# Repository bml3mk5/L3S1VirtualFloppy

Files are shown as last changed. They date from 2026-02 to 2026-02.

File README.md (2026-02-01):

# バーチャルフロッピーカード for 日立ベーシックマスターレベル3 / MB-S1

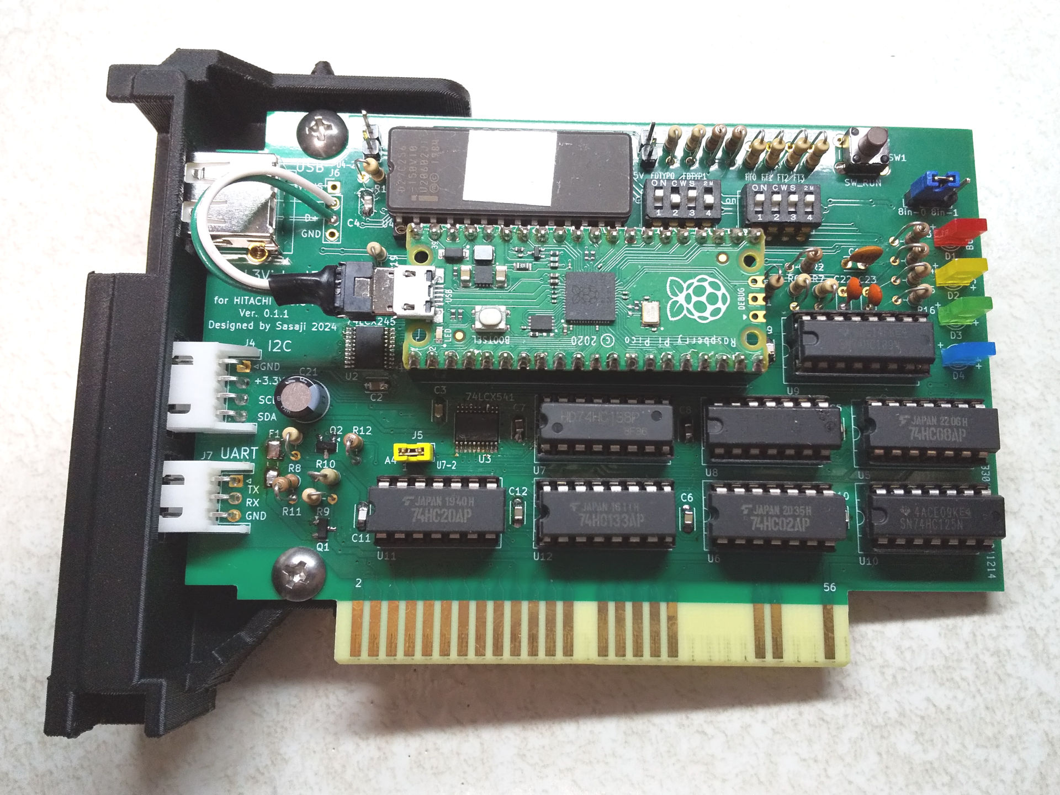
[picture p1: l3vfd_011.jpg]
L3VirtualFloppy Main

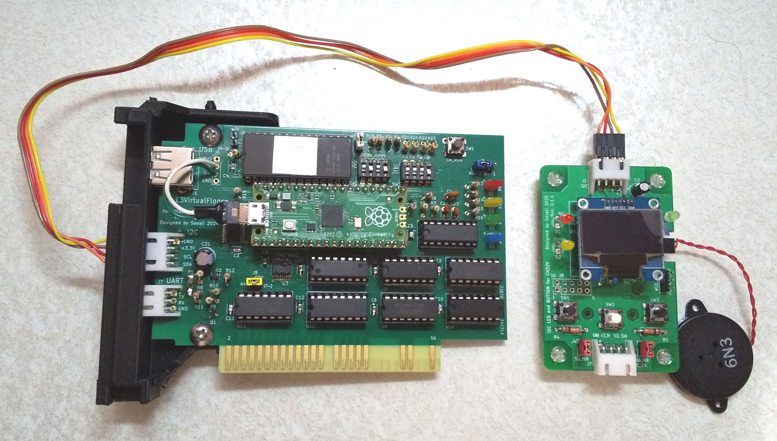
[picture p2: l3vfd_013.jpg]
L3VirtualFloppy Main + Controller

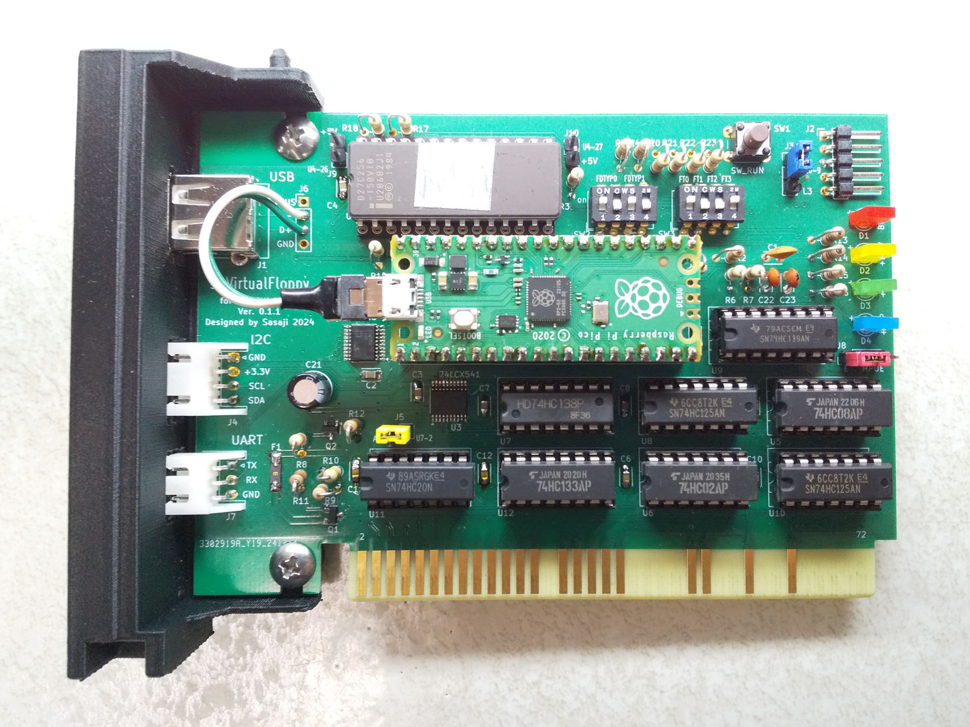
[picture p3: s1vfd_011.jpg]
S1VirtualFloppy Main

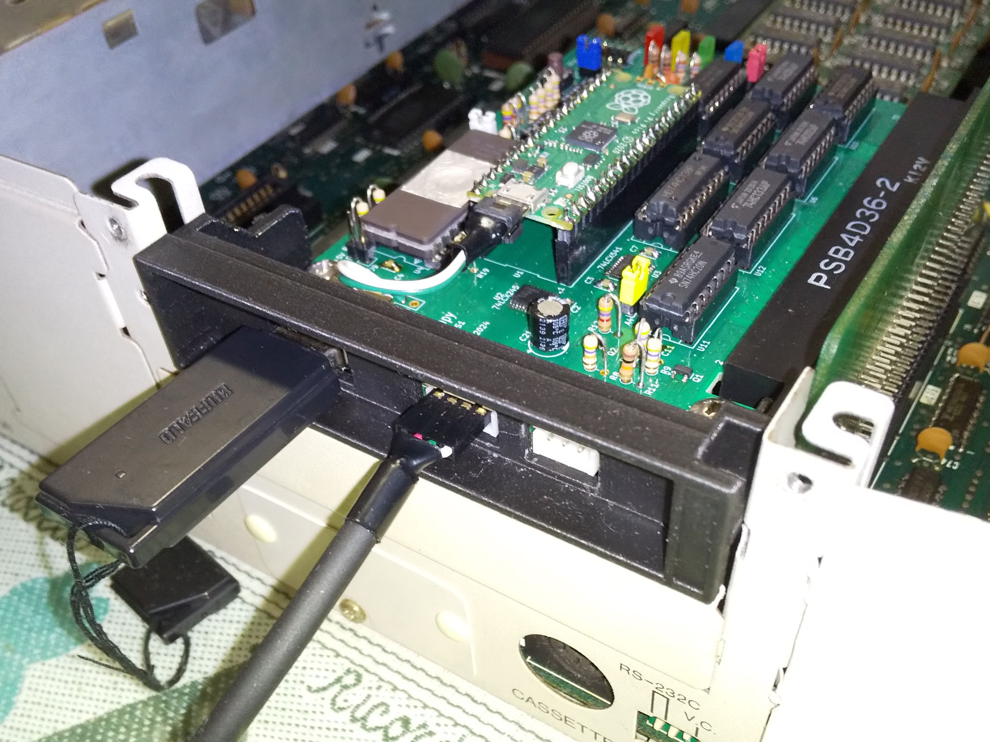
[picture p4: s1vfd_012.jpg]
S1VirtualFloppy Installed

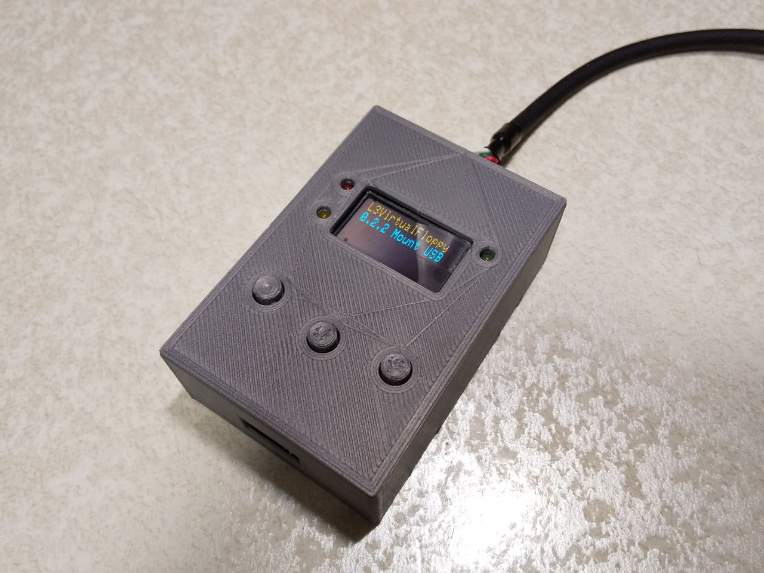
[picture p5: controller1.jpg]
Controller


## フォルダ構成

    3DModel/ ....................... 背面カバーの3Dモデル
      BML3/ .......................... 日立ベーシックマスターレベル3用の3Dモデル
      MBS1/ .......................... 日立MB-S1用の3Dモデル
    Board/ ......................... 基板設計
      BML3/ .......................... 日立ベーシックマスターレベル3用の基板設計
      MBS1/ .......................... 日立MB-S1用の基板設計
    Documents/ ..................... 説明書など
      BML3/ .......................... 日立ベーシックマスターレベル3用の説明書
      MBS1/ .......................... 日立MB-S1用の説明書
    Software/ ...................... ソフトウェア
      Controller/ .................... 本体カード用コントローラー
      Main/ .......................... 本体用(Pico SDK v2.0.0 + Visual Code(Cmake))
        pico_l3/ ....................... 日立ベーシックマスターレベル3用のソフトウェア
        pico_s1/ ....................... 日立MB-S1用のソフトウェア

-----
# Virtual Floppy Card for HITACHI Basic Master Level3 / MB-S1

## Folders

    3DModel/ ....................... The 3d models of back cover
      BML3/ .......................... for HITACHI Basic Master Level3
      MBS1/ .......................... for HITACHI MB-S1
    Board/ ......................... The circuit board design
      BML3/ .......................... for HITACHI Basic Master Level3
      MBS1/ .......................... for HITACHI MB-S1
    Documents/ ..................... Documents
      BML3/ .......................... for HITACHI Basic Master Level3
      MBS1/ .......................... for HITACHI MB-S1
    Software/ ...................... Software
      Controller/ .................... Controller for main card
      Main/ .......................... Main card (Pico SDK v2.0.0 + Visual Code(Cmake))
        pico_l3/ ....................... for HITACHI Basic Master Level3
        pico_s1/ ....................... for HITACHI MB-S1

-----
 MailTo: Sasaji (sasaji@s-sasaji.ddo.jp)
 * My Webpage: http://s-sasaji.ddo.jp/bml3mk5/
 * GitHub:     https://github.com/bml3mk5/L3S1VirtualFloppy
 * X(Twitter): https://x.com/bml3mk5

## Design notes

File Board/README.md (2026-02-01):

# バーチャルフロッピーカード for 日立ベーシックマスターレベル3 / MB-S1 基板設計

## 使用ツール

 * KiCAD 8

## フォルダ構成

    BML3/ .......................... 日立ベーシックマスターレベル3用
    Controller/ .................... 本体カード用コントローラー
    MBS1/ .......................... 日立MB-S1用

-----
# The Circuit Board Design of the Virtual Floppy Card for HITACHI Basic Master Level3 / MB-S1

## Using Tools

 * KiCAD 8

## Folders

    BML3/ .......................... for HITACHI Basic Master Level3
    Controller/ .................... Controller for main card
    MBS1/ .......................... for HITACHI MB-S1

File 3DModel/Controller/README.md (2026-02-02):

# ケースの3Dモデル for コントローラー

    I2C_LED_BTN.FCStd ........... FreeCAD 1.0を使用した3Dモデル設計ファイル

 * ケース上側

       I2C_LED_BTN-Body.3mf ........ UltiMaker Cura 5.9の設定ファイル
       I2C_LED_BTN-Body.stl ........ FreeCADからエクスポートした3Dモデル
       I2C_LED_BTN-Body.gcode ...... 3Dプリンター(Anycube Mega Zero 2.0)用Gcode

 * ケース下側

       I2C_LED_BTN-Body001.3mf ..... UltiMaker Cura 5.9の設定ファイル
       I2C_LED_BTN-Body001.stl ..... FreeCADからエクスポートした3Dモデル
       I2C_LED_BTN-Body001.gcode ... 3Dプリンター(Anycube Mega Zero 2.0)用Gcode

 * ボタン部分

       I2C_LED_BTN-Body002.3mf ..... UltiMaker Cura 5.9の設定ファイル
       I2C_LED_BTN-Body002.stl ..... FreeCADからエクスポートした3Dモデル
       I2C_LED_BTN-Body002.gcode ... 3Dプリンター(Anycube Mega Zero 2.0)用Gcode

-----
# The 3D models of enclosure for controller

    I2C_LED_BTN.FCStd ........... 3D model design file using FreeCAD 1.0

 * Upper side

       I2C_LED_BTN-Body.3mf ........ Configure file on UltiMaker Cura 5.9
       I2C_LED_BTN-Body.stl ........ Exported 3d model from FreeCAD
       I2C_LED_BTN-Body.gcode ...... Gcode for 3D printer (Anycube Mega Zero 2.0)

 * Lower side

       I2C_LED_BTN-Body001.3mf ..... Configure file on UltiMaker Cura 5.9
       I2C_LED_BTN-Body001.stl ..... Exported 3d model from FreeCAD
       I2C_LED_BTN-Body001.gcode ... Gcode for 3D printer (Anycube Mega Zero 2.0)

 * Parts of the button

       I2C_LED_BTN-Body002.3mf ..... Configure file on UltiMaker Cura 5.9
       I2C_LED_BTN-Body002.stl ..... Exported 3d model from FreeCAD
       I2C_LED_BTN-Body002.gcode ... Gcode for 3D printer (Anycube Mega Zero 2.0)

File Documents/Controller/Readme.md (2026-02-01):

# Controller for Virtual Floppy

## [組立説明書](Assemble_ja.pdf)

## [取扱説明書](Manual_ja.pdf)

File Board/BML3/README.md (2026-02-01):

# 基板設計 for L3VirtualFloppy

## 使用ツール

 * KiCAD 8

## ファイル

    L3VirtualFloppy.kicad_pro ..... プロジェクトファイル for KiCAD
    L3VirtualFloppy.kicad_sch ..... 回路図ファイル for KiCAD
    L3VirtualFloppy.kicad_pcb ..... PCB設計ファイル for KiCAD
    *.kicad_sym ................... シンボルファイル
    *.pretty/ ..................... フットプリントファイル
    *.wrl ......................... 3Dモデルファイル(3Dビュー用)
    gerber_jlc/ ................... ガーバーファイル for JLCPCB

-----
# The Circuit Board Design for L3VirtualFloppy

## Using Tools

 * KiCAD 8

## Files

    L3VirtualFloppy.kicad_pro ..... Project file for KiCAD
    L3VirtualFloppy.kicad_sch ..... Schematics file for KiCAD
    L3VirtualFloppy.kicad_pcb ..... PCB design file for KiCAD
    *.kicad_sym ................... Symbol file
    *.pretty/ ..................... Footprint files
    *.wrl ......................... 3Dmodel file(to use on 3D view)
    gerber_jlc/ ................... Gerber files for JLCPCB

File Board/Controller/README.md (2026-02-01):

# 基板設計 for コントローラー

## 使用ツール

 * KiCAD 8

## ファイル

    I2C_LED_BTN_CH32V.kicad_pro ... プロジェクトファイル for KiCAD
    I2C_LED_BTN_CH32V.kicad_sch ... 回路図ファイル for KiCAD
    I2C_LED_BTN_CH32V.kicad_pcb ... PCB設計ファイル for KiCAD
    *.pretty/ ..................... フットプリントファイル
    *.wrl ......................... 3Dモデルファイル(3Dビュー用)
    gerber_jlc/ ................... ガーバーファイル for JLCPCB

-----
# The Circuit Board Design for Controller

## Using Tools

 * KiCAD 8

## Files

    I2C_LED_BTN_CH32V.kicad_pro ... Project file for KiCAD
    I2C_LED_BTN_CH32V.kicad_sch ... Schematics file for KiCAD
    I2C_LED_BTN_CH32V.kicad_pcb ... PCB design file for KiCAD
    *.pretty/ ..................... Footprint files
    *.wrl ......................... 3Dmodel file(to use on 3D view)
    gerber_jlc/ ................... Gerber files for JLCPCB

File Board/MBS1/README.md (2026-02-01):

# 基板設計 for S1VirtualFloppy

## 使用ツール

 * KiCAD 8

## ファイル

    S1VirtualFloppy.kicad_pro ..... プロジェクトファイル for KiCAD
    S1VirtualFloppy.kicad_sch ..... 回路図ファイル for KiCAD
    S1VirtualFloppy.kicad_pcb ..... PCB設計ファイル for KiCAD
    *.kicad_sym ................... シンボルファイル
    *.pretty/ ..................... フットプリントファイル
    *.wrl ......................... 3Dモデルファイル(3Dビュー用)
    gerber_jlc/ ................... ガーバーファイル for JLCPCB

-----
# The Circuit Board Design for S1VirtualFloppy

## Using Tools

 * KiCAD 8

## Files

    S1VirtualFloppy.kicad_pro ..... Project file for KiCAD
    S1VirtualFloppy.kicad_sch ..... Schematics file for KiCAD
    S1VirtualFloppy.kicad_pcb ..... PCB design file for KiCAD
    *.kicad_sym ................... Symbol file
    *.pretty/ ..................... Footprint files
    *.wrl ......................... 3Dmodel file(to use on 3D view)
    gerber_jlc/ ................... Gerber files for JLCPCB

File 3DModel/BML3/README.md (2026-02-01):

# 背面カバーの3Dモデル for L3VirtualFloppy

    L3BackSideVF2.FCStd ....... FreeCAD 1.0を使用した3Dモデル設計ファイル
    L3BackSideVF2-Body.3mf .... UltiMaker Cura 5.9の設定ファイル
    L3BackSideVF2-Body.stl .... FreeCADからエクスポートした3Dモデル
    L3BackSideVF2-Body.wrl .... FreeCADからエクスポートした3Dモデル(kicad 3Dビューで使用)
    MegaZero2.0/ .............. 3Dプリンター(Anycube Mega Zero 2.0)用Gcode

-----
# The 3D Models of Back Cover for L3VirtualFloppy

    L3BackSideVF2.FCStd ....... 3D model design file using FreeCAD 1.0
    L3BackSideVF2-Body.3mf .... Configure file on UltiMaker Cura 5.9
    L3BackSideVF2-Body.stl .... Exported 3d model from FreeCAD
    L3BackSideVF2-Body.wrl .... Exported 3d model from FreeCAD (to use on kicad 3d view)
    MegaZero2.0/ .............. Gcode for 3D printer (Anycube Mega Zero 2.0)

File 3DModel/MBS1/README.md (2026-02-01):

# 背面カバーの3Dモデル for S1VirtualFloppy

    S1BackSideVF.FCStd ........ FreeCAD 1.0を使用した3Dモデル設計ファイル
    S1BackSideVF-Body.3mf ..... UltiMaker Cura 5.9の設定ファイル
    S1BackSideVF-Body.stl ..... FreeCADからエクスポートした3Dモデル
    S1BackSideVF-Body.wrl ..... FreeCADからエクスポートした3Dモデル(kicad 3Dビューで使用)
    MegaZero2.0/ .............. 3Dプリンター(Anycube Mega Zero 2.0)用Gcode

-----
# The 3D Models of Back Cover for S1VirtualFloppy

    S1BackSideVF.FCStd ........ 3D model design file using FreeCAD 1.0
    S1BackSideVF-Body.3mf ..... Configure file on UltiMaker Cura 5.9
    S1BackSideVF-Body.stl ..... Exported 3d model from FreeCAD
    S1BackSideVF-Body.wrl ..... Exported 3d model from FreeCAD (to use on kicad 3d view)
    MegaZero2.0/ .............. Gcode for 3D printer (Anycube Mega Zero 2.0)

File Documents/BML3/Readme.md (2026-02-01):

# L3VirtualFloppy

## [Assembly Instruction](Assemble_en.pdf)
## [組立説明書](Assemble_ja.pdf)

## [User's Manual](Manual_en.pdf)
## [取扱説明書](Manual_ja.pdf)

## [Schematics](L3VirtualFloppy_sch.png)
## [回路図](L3VirtualFloppy_sch.png)

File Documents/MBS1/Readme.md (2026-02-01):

# S1VirtualFloppy

## [Assembly Instruction](Assemble_en.pdf)
## [組立説明書](Assemble_ja.pdf)

## [User's Manual](Manual_en.pdf)
## [取扱説明書](Manual_ja.pdf)

## [Schematics](S1VirtualFloppy_sch.png)
## [回路図](S1VirtualFloppy_sch.png)

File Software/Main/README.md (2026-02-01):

# バーチャルフロッピーカード for 日立ベーシックマスターレベル3 / MB-S1

## 使用ツール

 * VS Code
   + Raspberry Pi Pico SDK

## ビルド方法

 * 日立ベーシックマスターレベル3用のファームウェアをビルドする場合は、VS Code
   からpico_l3フォルダを開いてください。
 * 日立MB-S1用のファームウェアをビルドする場合は、VS Codeからpico_s1フォルダ
   を開いてください。

## フォルダ構成

    pico_l3/ ....................... 日立ベーシックマスターレベル3用
      build/ ......................... ビルド済みファームウェア
    pico_s1/ ....................... 日立MB-S1用ビルド
      build/ ......................... ビルド済みファームウェア
    src/ ........................... ソースコード

-----
# Virtual Floppy Card for HITACHI Basic Master Level3 / MB-S1

## Using Tools

 * VS Code
   + Raspberry Pi Pico SDK

## How to build

 * If you're building firmware for the Hitachi Basic Master Level3, open
   the pico_l3 folder in VS Code.
 * If you're building firmware for the Hitachi MB-S1, open the pico_s1 folder
   in VS Code.

## Folders

    pico_l3/ ....................... for HITACHI Basic Master Level3
      build/ ......................... Built firmware
    pico_s1/ ....................... for HITACHI MB-S1
      build/ ......................... Built firmware
    src/ ........................... Source codes

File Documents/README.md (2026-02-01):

# バーチャルフロッピーカード for 日立ベーシックマスターレベル3 / MB-S1 ドキュメント

## フォルダ構成

    BML3/ .......................... 日立ベーシックマスターレベル3用
    Controller/ .................... 本体カード用コントローラー
    MBS1/ .......................... 日立MB-S1用

-----
# Documents of Virtual Floppy Card for HITACHI Basic Master Level3 / MB-S1

## Folders

    BML3/ .......................... for HITACHI Basic Master Level3
    Controller/ .................... Controller for main card
    MBS1/ .......................... for HITACHI MB-S1

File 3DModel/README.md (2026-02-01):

# バーチャルフロッピーカード for 日立ベーシックマスターレベル3 / MB-S1 3Dモデル

## 使用ツール

 * FreeCAD 1.0
 * UltiMaker Cura 5.9

## フォルダ構成

    BML3/ .......................... 日立ベーシックマスターレベル3用
    Controller/ .................... コントローラー for 本体カード
    MBS1/ .......................... 日立MB-S1用ビルド

-----
# The 3D Models of Virtual Floppy Card for HITACHI Basic Master Level3 / MB-S1

## Using Tools

 * FreeCAD 1.0
 * UltiMaker Cura 5.9

## Folders

    BML3/ .......................... for HITACHI Basic Master Level3
    Controller/ .................... Controller for main card
    MBS1/ .......................... for HITACHI MB-S1

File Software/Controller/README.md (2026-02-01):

# バーチャルフロッピーカード用コントローラー

## 使用ツール

 * VS Code
   + PlatformIO IDE
     + CH32Vの拡張機能をインストール

## フォルダ

    .pio/
      build/
        genericCH32V003F4P6/ ....... ファームウェア
    src/ ........................... ソースコード

-----
# Controller for Virtual Floppy Card

## Using Tools

 * VS Code
   + PlatformIO IDE
     + Install the advanced platform for CH32V

## Folders

    .pio/
      build/
        genericCH32V003F4P6/ ....... Firm ware
    src/ ........................... Source codes

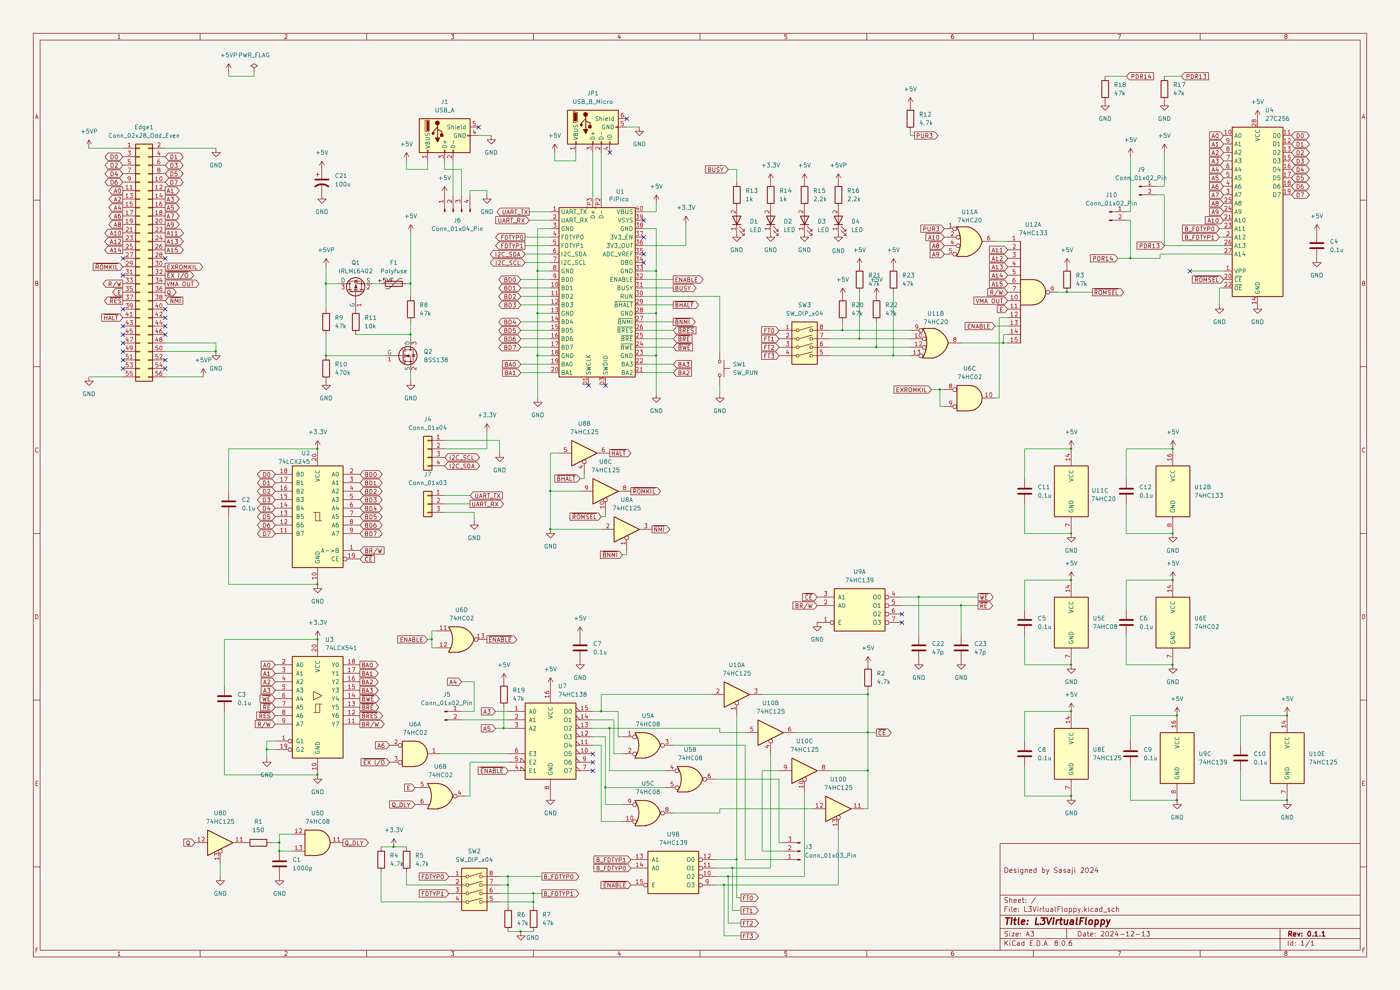
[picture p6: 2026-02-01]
Documents/BML3/L3VirtualFloppy_sch.png

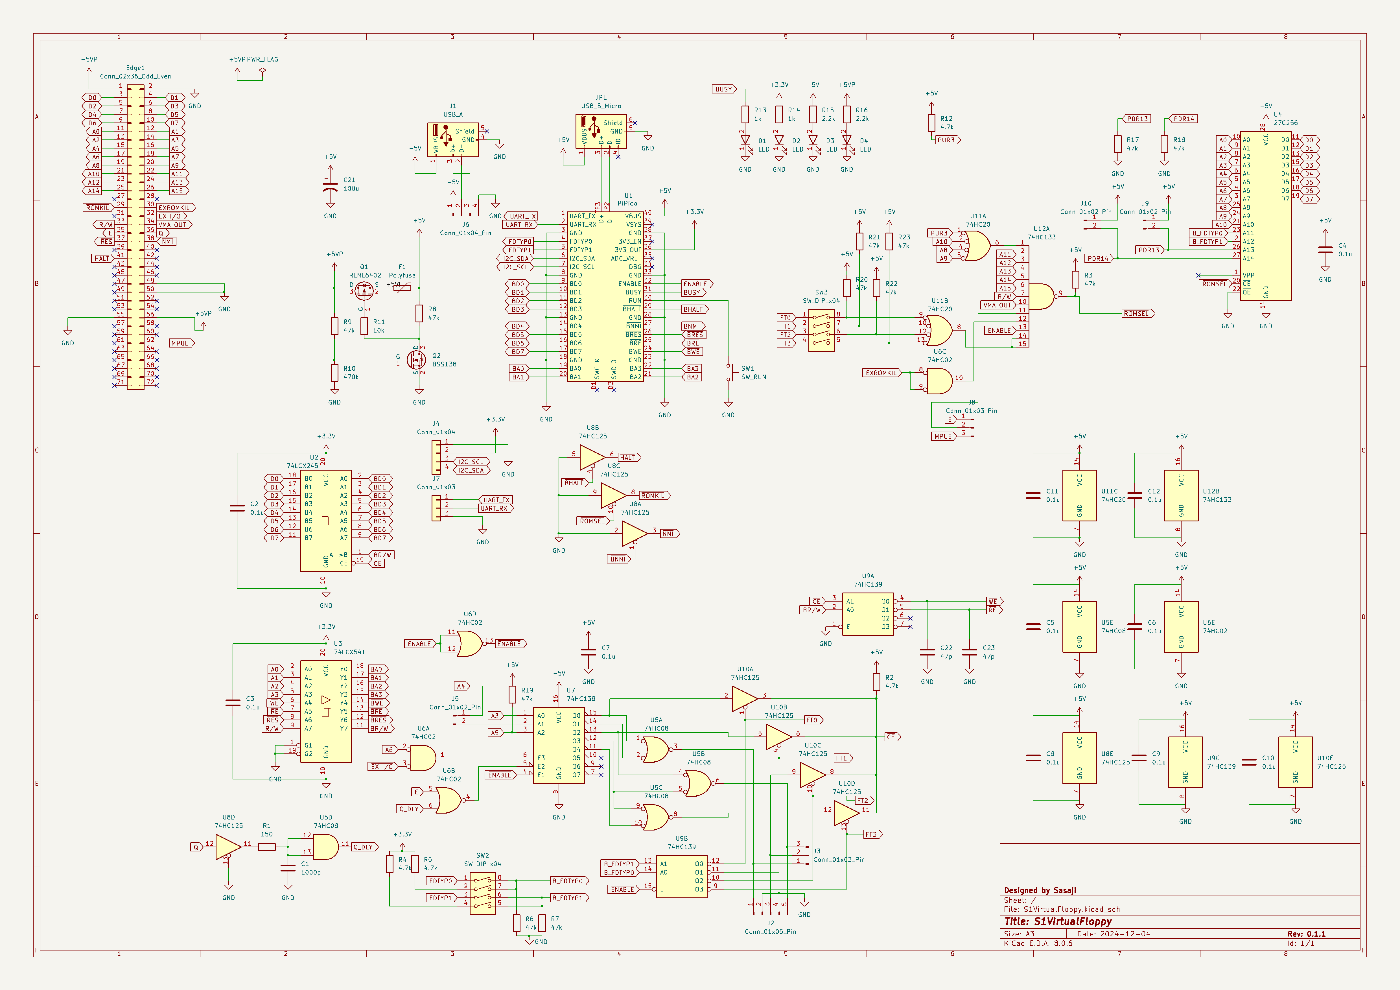
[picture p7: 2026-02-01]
Documents/MBS1/S1VirtualFloppy_sch.png

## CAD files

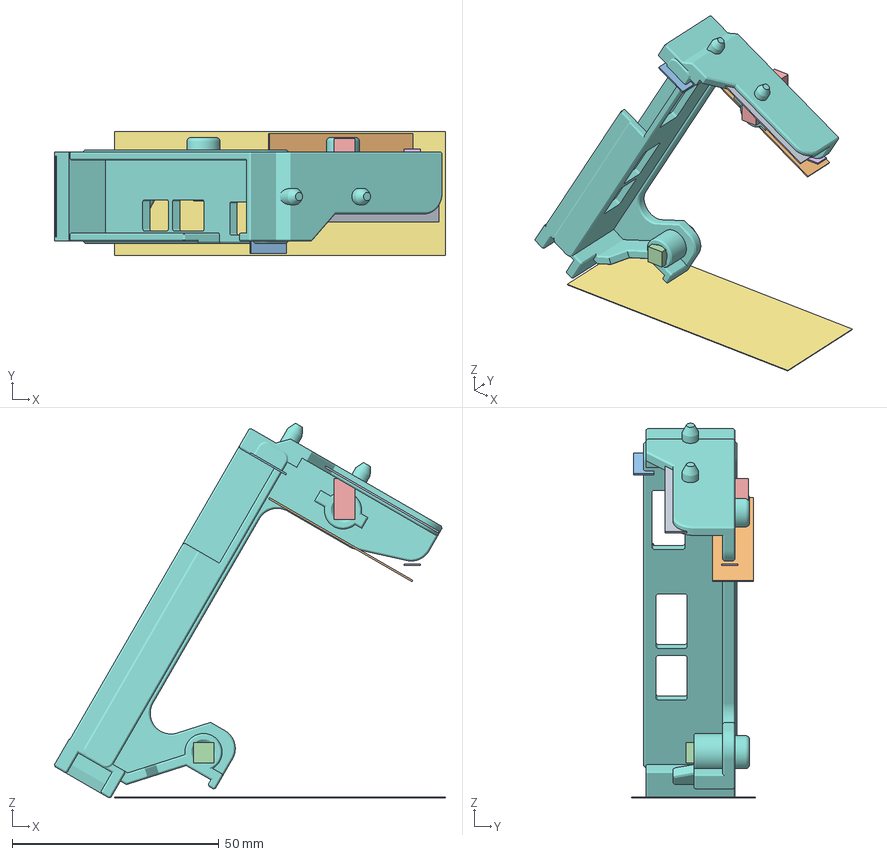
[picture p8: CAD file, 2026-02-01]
3DModel/BML3/L3BackSideVF2-Body.3mf
94.5 x 30.0 x 90.6 mm
Square5-Body.stl
Square5-Body.stl(1)
Square5-Body.stl(2)
Square5-Body.stl(3)
Square5-Body.stl(4)
Square5-Body.stl(5)
Square5-Body.stl(6)
L3BackSideVF2-Body.stl

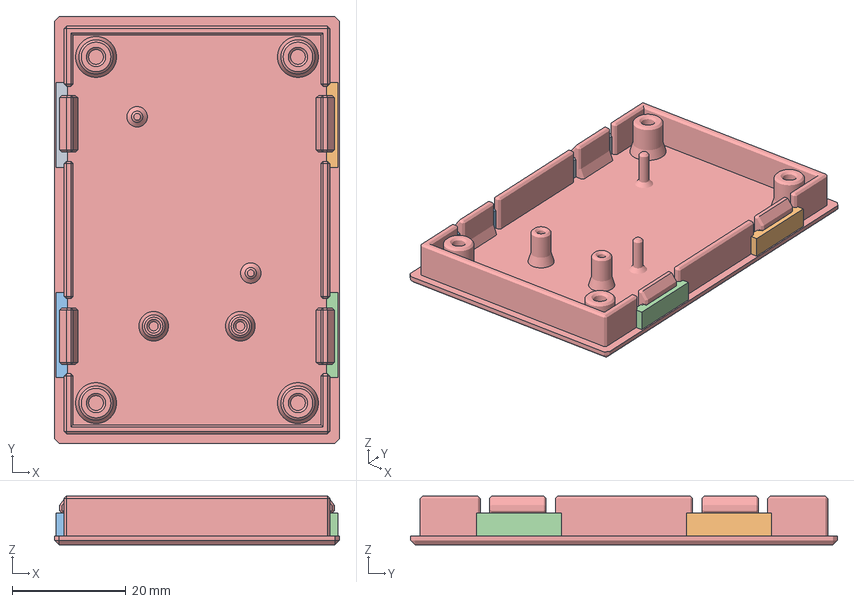
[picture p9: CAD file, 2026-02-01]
3DModel/Controller/I2C_LED_BTN-Body001.3mf
50.2 x 75.2 x 8.60 mm
Square5-Body.stl
Square5-Body.stl(1)
Square5-Body.stl(2)
Square5-Body.stl(3)
I2C_LED_BTN-Body001.stl

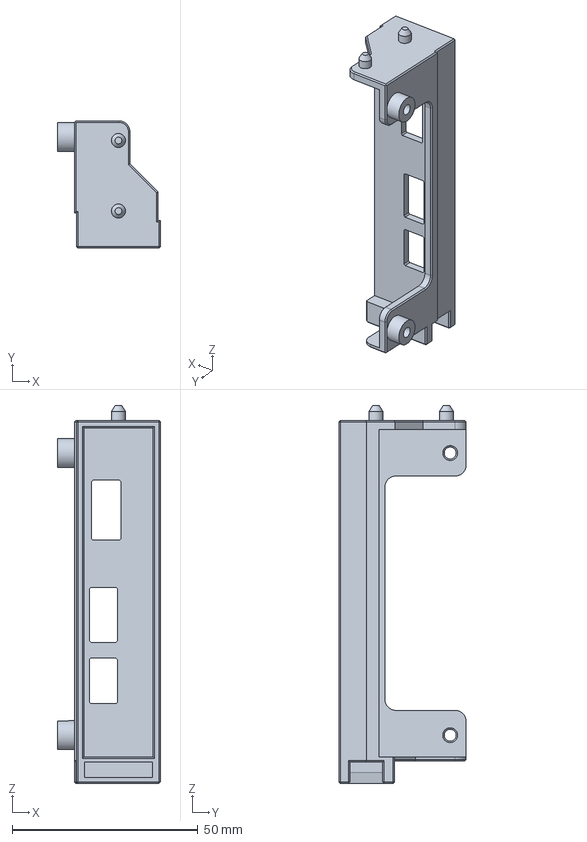
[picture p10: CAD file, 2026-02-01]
3DModel/MBS1/S1BackSideVF.FCStd
27.7 x 34.3 x 101.8 mm

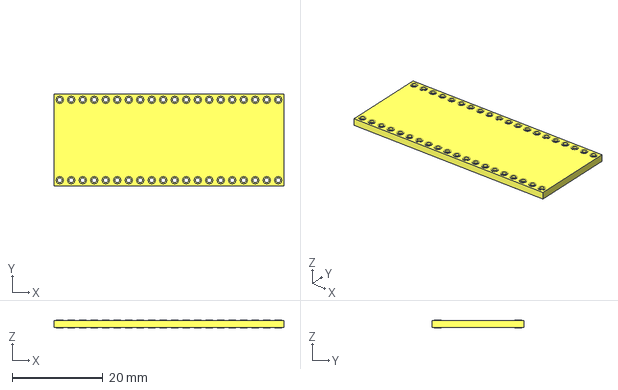
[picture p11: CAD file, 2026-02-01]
Board/BML3/3dmodel/PiPico1-Body001.step
50.8 x 20.3 x 1.80 mm

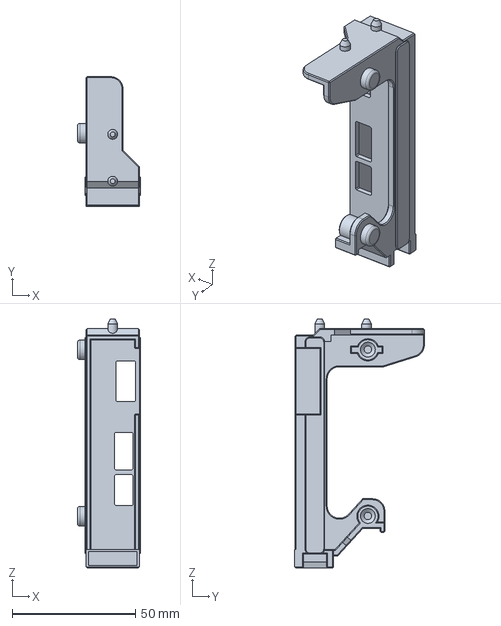
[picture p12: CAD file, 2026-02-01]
3DModel/BML3/L3BackSideVF2.FCStd
25.6 x 52.6 x 101.0 mm

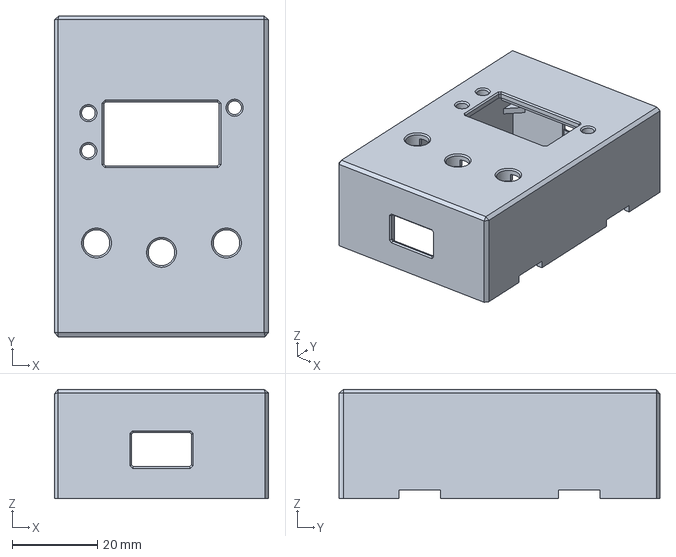
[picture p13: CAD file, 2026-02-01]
3DModel/Controller/I2C_LED_BTN.FCStd
50.2 x 75.2 x 25.6 mm

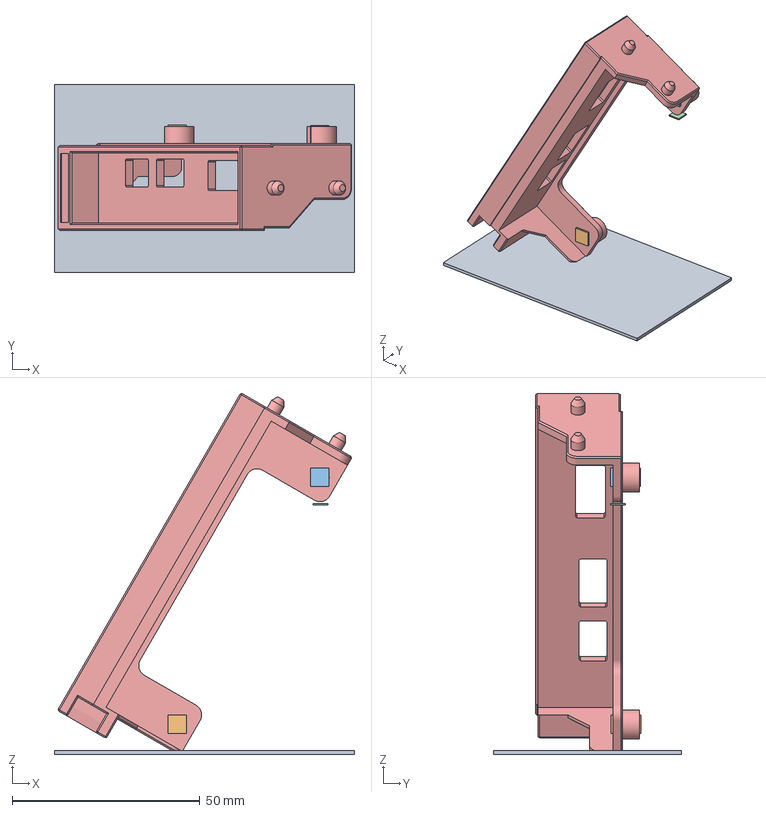
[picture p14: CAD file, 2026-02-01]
3DModel/MBS1/S1BackSideVF-Body.3mf
80.0 x 50.0 x 96.3 mm
Square5-Body.stl
Square5-Body.stl(1)
Square5-Body.stl(2)
Square5-Body.stl(3)
S1BackSideVF-Body.stl

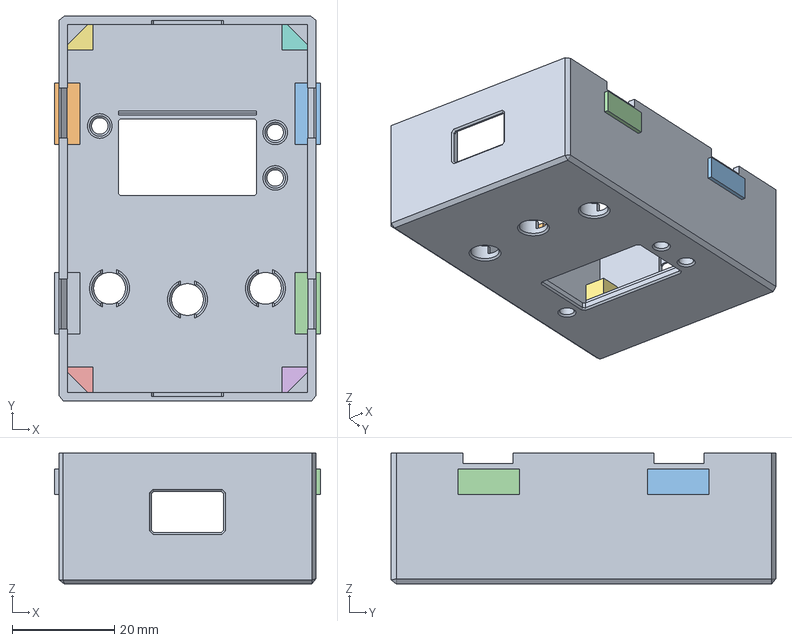
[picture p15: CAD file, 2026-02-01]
3DModel/Controller/I2C_LED_BTN-Body.3mf
52.0 x 75.2 x 25.6 mm
Square5-Body.stl
Square5-Body.stl(1)
Square5-Body.stl(2)
Square5-Body.stl(3)
Square5-Body.stl(4)
Square5-Body.stl(5)
Square5-Body.stl(6)
Square5-Body.stl(7)
I2C_LED_BTN-Body.stl

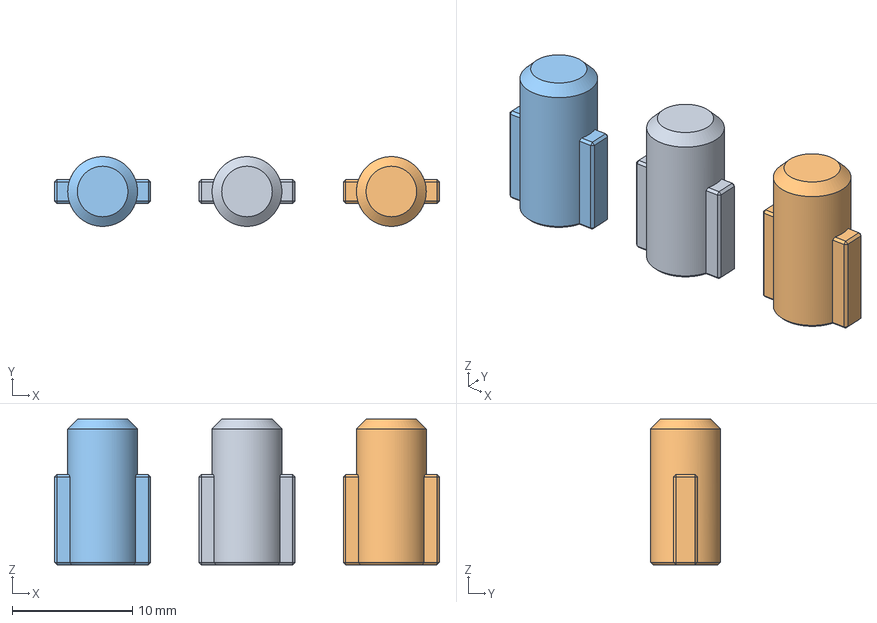
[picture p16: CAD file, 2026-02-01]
3DModel/Controller/I2C_LED_BTN-Body002.3mf
32.0 x 5.80 x 12.1 mm
I2C_LED_BTN-Body002.stl
I2C_LED_BTN-Body002.stl(3)
I2C_LED_BTN-Body002.stl(4)

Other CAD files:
3DModel/BML3/L3BackSideVF2-Body.stl
3DModel/Controller/I2C_LED_BTN-Body.stl
3DModel/Controller/I2C_LED_BTN-Body001.stl
3DModel/Controller/I2C_LED_BTN-Body002.stl
3DModel/MBS1/S1BackSideVF-Body.stl

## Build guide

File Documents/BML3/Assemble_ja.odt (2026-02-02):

日立ベーシックマスターレベル３用

L3VirtualFloppyカード 組立説明書

Designed by Sasaji 2024-2025 Rev. 0.1.1

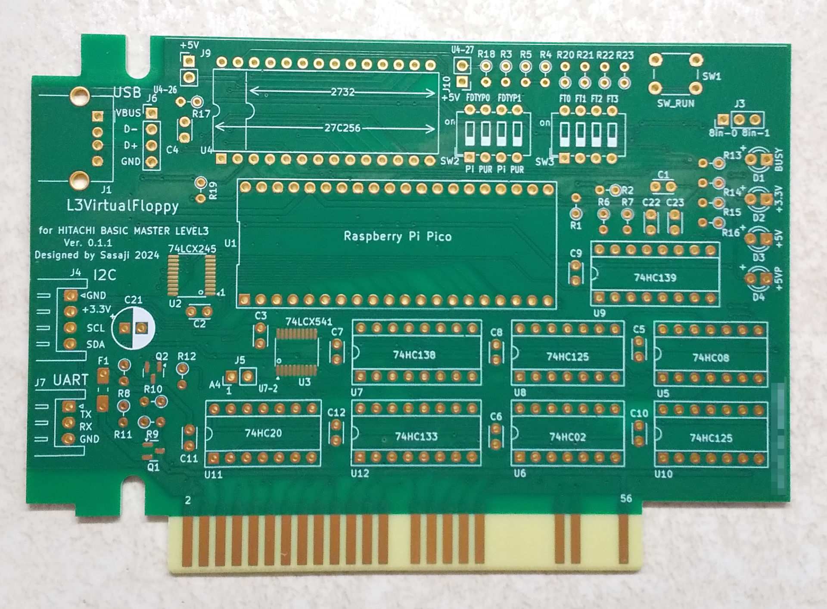
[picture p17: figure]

# 部品表

表 1: 基本部品

番号 | 部品名 | 数量 | 値など
C1 | セラミックコンデンサ | 1 | 1000pF
C2,C3,C5,C6,C7,C8,C9,C10 | セラミックコンデンサ | 8 | 0.1uF
C21 | 電解コンデンサ | 1 | 100uF, 16V～
C22,C23 | セラミックコンデンサ | 2 | 47pF
R1 | カーボン抵抗 | 1 | 150Ω, 1/4W～
R2,R4,R5,R12 | カーボン抵抗 | 4 | 4.7KΩ, 1/6W～
R3 | カーボン抵抗 | 1 | 47KΩ, 1/6W～ (10KΩ～47KΩで使用可能)
R6,R7,R8,R9, R19,R24* | カーボン抵抗 | 6 | 47KΩ, 1/6W～ (22KΩ～47KΩで使用可能)
R10 | カーボン抵抗 | 1 | 470KΩ, 1/6W～
R11 | カーボン抵抗 | 1 | 10KΩ, 1/6W～
F1 | リセッタブルヒューズ / ポリスイッチ | 1 | トリップ電流500mA～750mAのもの 表面実装とスルーホールどちらでも可能。
Q1 | MOSFET Pch | 1 | パワーMOSFET Pチャンネル IRLML6402など, SOT23
Q2 | MOSFET Nch | 1 | MOSFET Nチャンネル BSS138など, SOT23
U1 | Raspberry Pi Pico | 1 | ラズパイPico
U2 | CMOSロジックIC | 1 | 74LCX245, SSOP20ピン
U3 | CMOSロジックIC | 1 | 74LCX541, SSOP20ピン
U5 | CMOSロジックIC | 1 | 74HC08, DIP14ピン
U6 | CMOSロジックIC | 1 | 74HC02, DIP14ピン
U7 | CMOSロジックIC | 1 | 74HC138, DIP16ピン
U8,U10 | CMOSロジックIC | 2 | 74HC125, DIP14ピン
U9 | CMOSロジックIC | 1 | 74HC139, DIP16ピン
SW1 | タクトスイッチ | 1 | 6mm x 6mmタイプ
SW2 | DIPスイッチ | 1 | 4回路, DIP8ピン
J3 | ピンヘッダ | 1 | ピンヘッダ 3ピンx1列 2.54mmピッチ ストレート
J4 | XHコネクタ | 1 | 4ピンx1列 2.5mmピッチ Lアングル JST S4B-XH-Aなど
J5 | ピンヘッダ | 1 | ピンヘッダ 2ピンx1列 2.54mmピッチ ストレート
U1_F1,U1_F2 | ピンソケット | 2 | ピンソケット 20ピンx1列 2.54mmピッチ ストレート Raspberry Pi Picoのピンとの接続用
| ジャンパピン | 2 | J3, J5用
U5S, U6S, U8S, U10S | ICソケット | 4 | DIP14ピン 任意
U7S, U9S | ICソケット | 2 | DIP16ピン 任意

*基板上のシルク印刷に記載がない部品

表 2: 基板上のUSB Aポートを使用する場合に必要な部品

番号 | 部品名 | 数量 | 値など
J1 | USB Aソケット | 1 | 基板取付用USBコネクタ Aタイプ メス (秋月 5075AR-04-WHなど)
| USB microBプラグ | 1 | ケーブル取付用USBコネクタ microBタイプ オス (秋月 MOUSB-5BM103AS など)
| ケーブル | 2 | 上記プラグとJ6とを接続。10cmぐらい USBのD+とD-を接続する必要があります。 (VUSBとGNDは基板上で接続済み)

表 3: ブート用ROMを実装する場合に必要な部品

番号 | 部品名 | 数量 | 値など
C4,C11,C12 | セラミックコンデンサ | 3 | 0.1uF
U4 | ROM | 1 | EPROM DIP28ピン 2764～27256, 27C64～27C256など
U11 | CMOSロジックIC | 1 | 74HC20, DIP14ピン
U12 | CMOSロジックIC | 1 | 74HC133, DIP16ピン
R17,R18,R20,R21,R22,R23 | カーボン抵抗 | 6 | 47KΩ, 1/6W～ (10KΩ～47KΩで使用可能)
SW3 | DIPスイッチ | 1 | 4回路, DIP8ピン
J9,J10 | ピンヘッダ | 2 | ROMのアドレス切換用 ピンヘッダ 2ピンx1列 2.54mmピッチ ストレート
| ジャンパピン | 1 | J9
U4S | ICソケット | 1 | DIP28ピン あったほうが良い
U11S | ICソケット | 1 | DIP14ピン 任意
U12S | ICソケット | 1 | DIP16ピン 任意

表 4: その他の部品（任意）

番号 | 部品名 | 数量 | 値など
D1 | LED | 1 | 3mmΦなど Raspberry Pi PicoがBUSYのとき点灯
D2 | LED | 1 | 3mmΦなど +3.3Vを供給しているとき点灯
D3 | LED | 1 | 3mmΦなど +5V(VUSB)を供給しているとき点灯
D4 | LED | 1 | 3mmΦなど パソコン側から+5Vを供給しているとき点灯
R13 | カーボン抵抗 | 1 | LED D1を実装する場合に必要。 470Ω～2.2KΩ, 1/4W～ (*)
R14 | カーボン抵抗 | 1 | LED D2を実装する場合に必要。 470Ω～2.2KΩ, 1/4W～ (*)
R15 | カーボン抵抗 | 1 | LED D3を実装する場合に必要。 1KΩ～3.3KΩ, 1/4W～ (*)
R16 | カーボン抵抗 | 1 | LED D4を実装する場合に必要。 1KΩ～3.3KΩ, 1/4W～ (*)
J7 | XHコネクタ | 1 | 3ピンx1列 2.5mmピッチ Lアングル JST S3B-XH-A など

* 抵抗値はLEDの明るさに応じて調整してください。

# 追加部品の実装について

この基板は設計ミスがありパッチが必要です。以下の部品を追加で実装してください。

## 抵抗R24の追加

以下の図のように、基板のハンダ面側にプルアップ抵抗R24を追加してください。

この抵抗はHALT時にR/W信号が不安定ならないようにするものです。

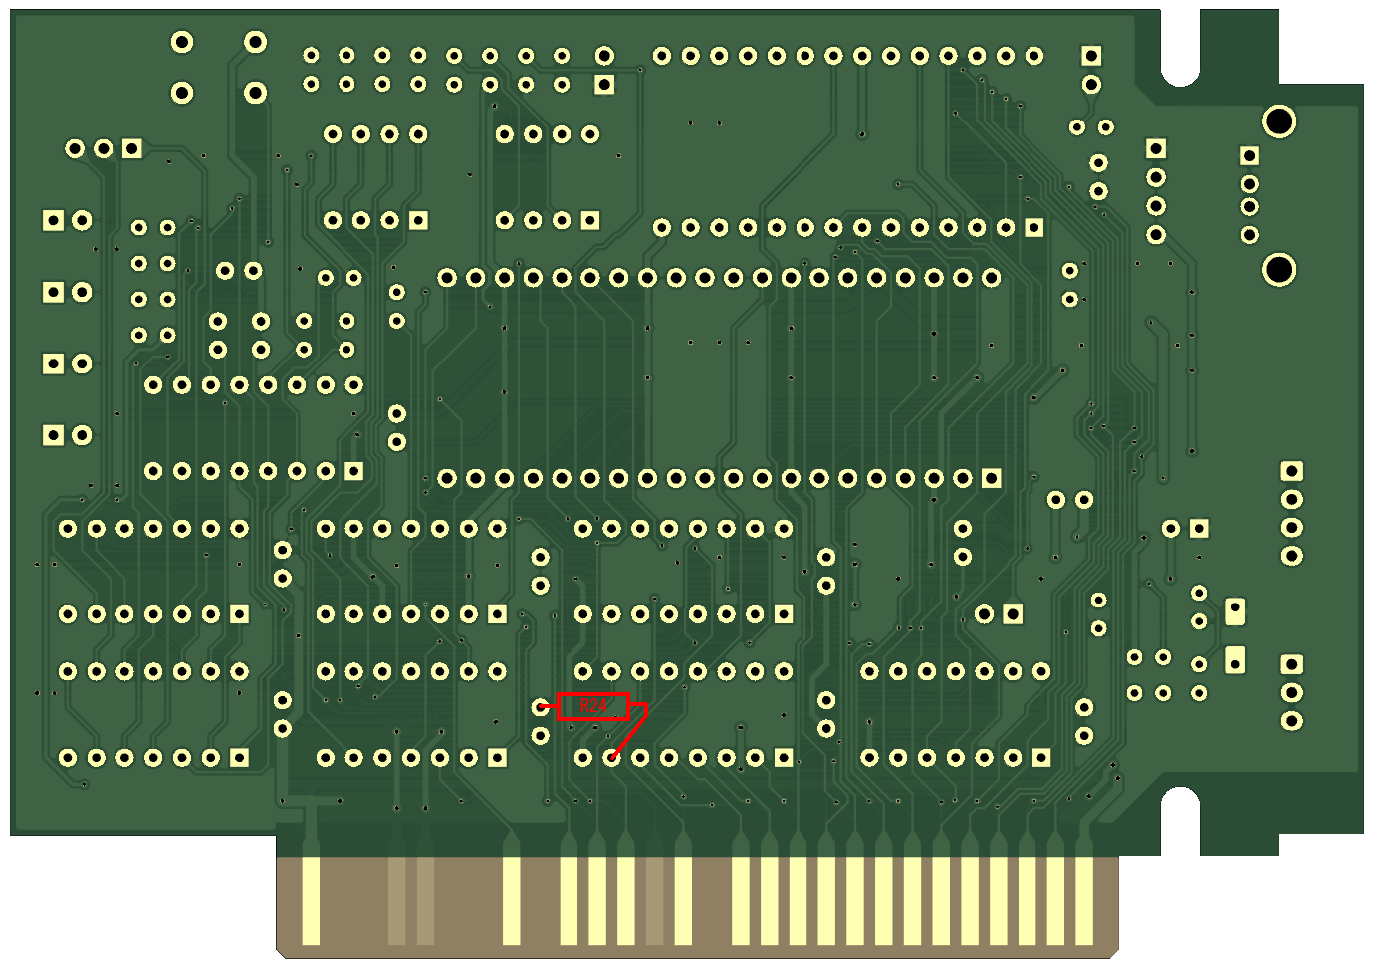
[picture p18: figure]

図 1: 基板のハンダ面（裏側）

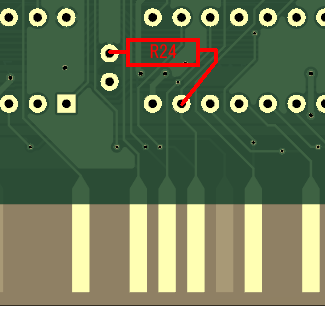
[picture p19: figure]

図 2: R24の取り付け方

# 基板上のUSB Aポートを使用するには

基板上のUSB Aポートを使えるようにするには、J6のD+,D-をRaspberry Pi PicoのUSBポートに接続する必要があります。以下のいずれかの方法で実装してください。

(VBUSとGNDはそれぞれ基板上でつながっているのでここを接続する必要はありません。)

## microBコネクタを使用する方法

表 2の部品を用意してください。

図 3のようにmicroBコネクタが付いたものを作成し、図 4のようにJ6とPicoのmicroBポートに接続します。

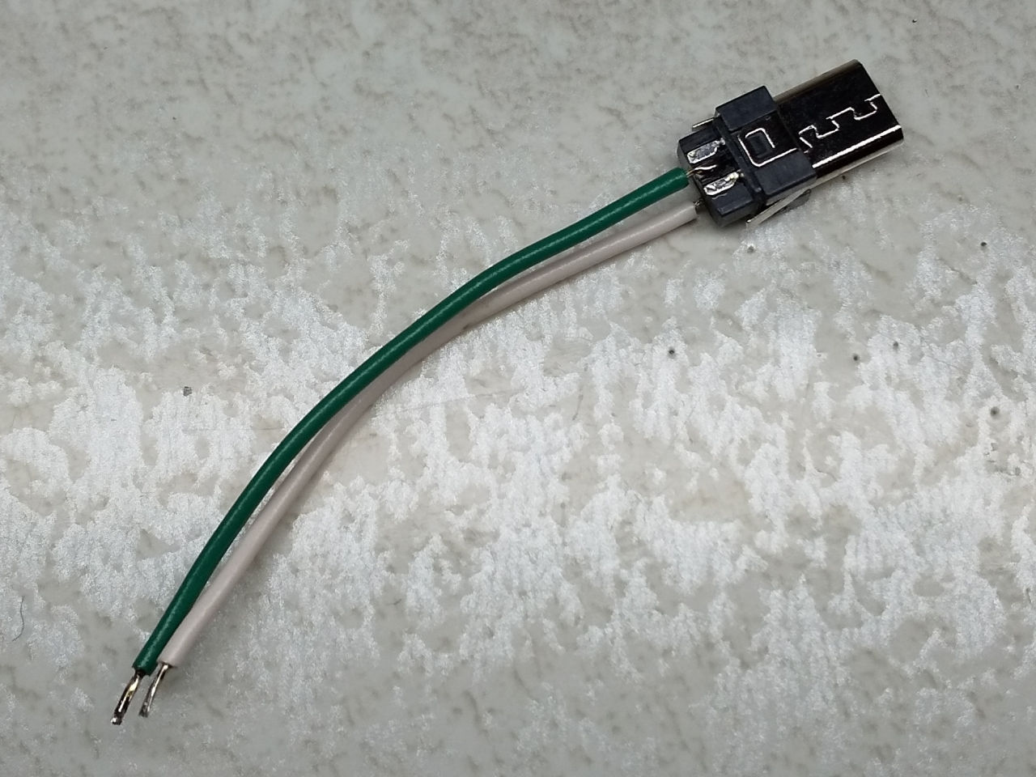
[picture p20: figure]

図 3: 秋月 MOUSB-5BM103ASとケーブルをはんだ付け。写真では緑(D+)を端子中央(ピン3)に、白(D-)を裏側の端子左側(ピン2)につないでいる。

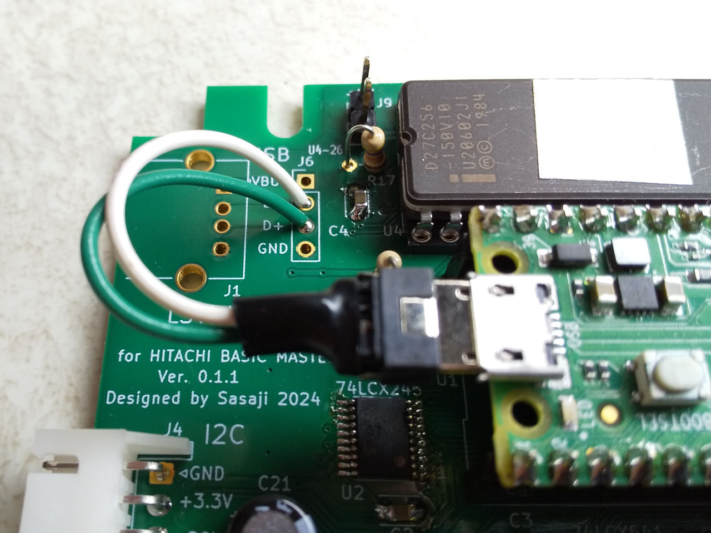
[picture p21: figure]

図 4: 基板にケーブルをはんだ付け。緑をD+、白をD-に接続している。

## Picoに直接はんだ付けする方法

J6とRaspberry Pi Pico裏側にあるTP2(D-),TP3(D+)にケーブルで直接はんだ付けします。

# ブート用ROMについて

5インチ2Dおよび8インチ2Dを使用する場合ブート用のROMを別途用意する必要があります。ROMの容量は8KB以上のものを推奨します。

## ROMイメージ

ROMの内容は以下のように書き込んだものを用意してください。

表 5: ROMの内容

| アドレス | 概要 | 詳細
0 | $0000～$07FF | 5インチ2DのブートROMイメージ | MP-1802に搭載されているROMのイメージ。
1 | $0800～$0FFF | 5インチ2DのブートROMイメージ | 上記と同じ。
2 | $1000～$17FF | 8インチ2DのブートROMイメージ | MP-1806に搭載されているROMのイメージ。 テストしていないため動作するかは不明。
3 | $1800～$1FFF | 3インチ1SのブートROMイメージ | MP-1800またはMP-1805に搭載されているROMのイメージ。 このイメージはレベル3のROMに標準で含まれているので無くてもよい。

- ROMのアクセスタイムは400ns以下のものを使用してください。

## 28ピンROMを使用する場合

### 8KBのROM(2764,27C64など)または16KBのROM(27C128など)使用時

ジャンパーJ10(ピン27(PGM)に接続)をショートさせてください。

16KBのROM使用時はジャンパーJ9でアドレスA13の選択ができます。ショートさせると”1”になります。通常はオープンにして下さい。

### 32KBのROM(27C256など)使用時

ジャンパーJ9,J10でアドレスを指定します。J9がA13, J10がA14となります。ショートさせると”1”になります。通常はオープンにしてください。

### 64KBのROM（27C512など）使用時

ピン1(A15)をGNDに接続してください。

ジャンパーJ9,J10の意味は32KBのROMと同じです。

## 24ピンROMを使用する場合

ジャンパーJ9をショートさせてください。ここから+5Vを供給します。ROMを基板上に実装する時はシルク印刷にあるように基板右側に寄せてください。

SW3でどのFD種類の時にROMを有効にするかを設定してください。

# 使い方

取扱説明書(Manual_ja.pdf)を参照してください。

# 免責事項

この基板によって発生したいかなる損害についても当方は一切責任を負いません。

この基板を使用するにあたってはすべて自己責任で行ってください。

改訂履歴

初版: 新規作成。

リンク先

この資料や基板データなどはGitHub(https://github.com/bml3mk5/) (https://github.com/bml3mk5/MP1802Gotek)に置いています。

MailTo: Sasaji (sasaji@s-sasaji.ddo.jp)

Web: http://s-sasaji.ddo.jp/bml3mk5/

X(Twitter): https://twitter.com/bml3mk5/

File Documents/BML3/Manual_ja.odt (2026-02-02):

日立ベーシックマスターレベル３用

L3VirtualFloppyカード　取扱説明書

Designed by Sasaji 2024-2026

Board Revision 0.1.1

Software Version 0.2.2

日立ベーシックマスターレベル３用仮想フロッピーディスクカードです。

レベル３実機からUSBメモリ内部にあるフロッピーディスクイメージに直接アクセスできます。


図 1: 外観

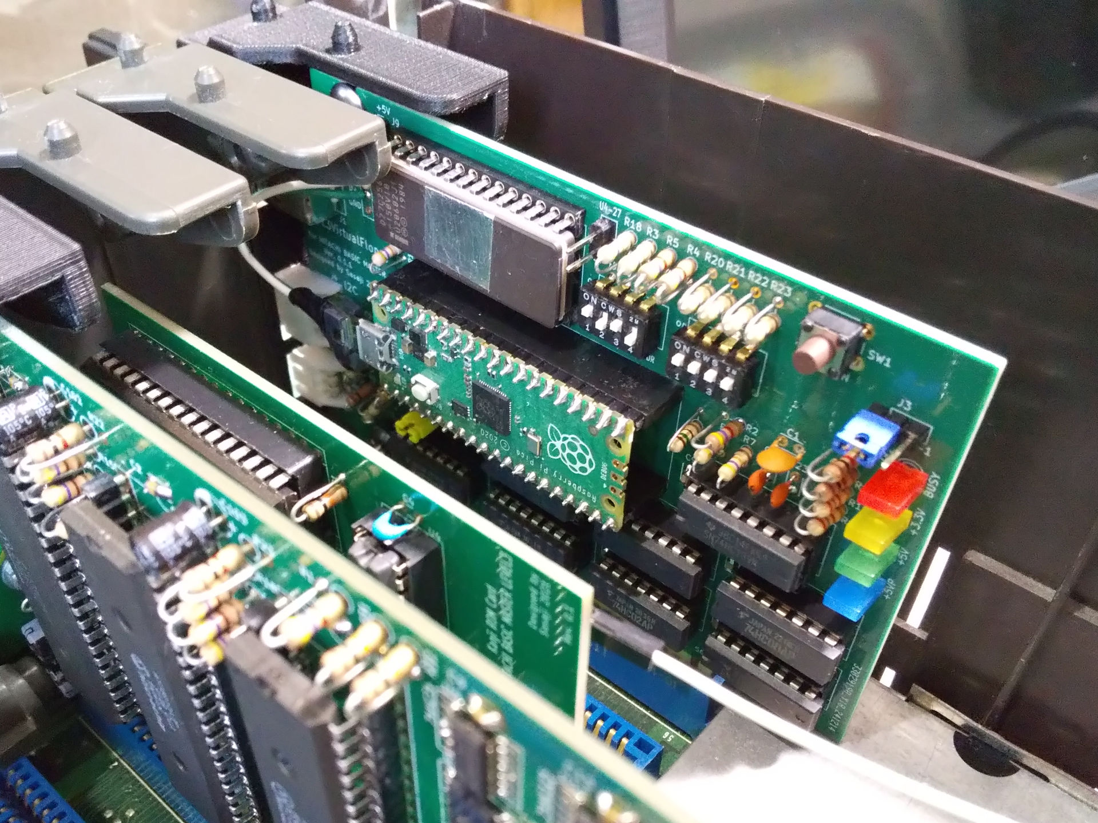
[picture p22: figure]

図 2: レベル３本体に実装したところ

# 必要なもの

## I2Cデバイス

仮想FDの状態表示やUSBメモリ内部のファイルを選択するためにI2Cで接続できるデバイスが必要です。

I2Cデバイスは3.3Vで駆動するものを使用してください。

### I2Cディスプレイ

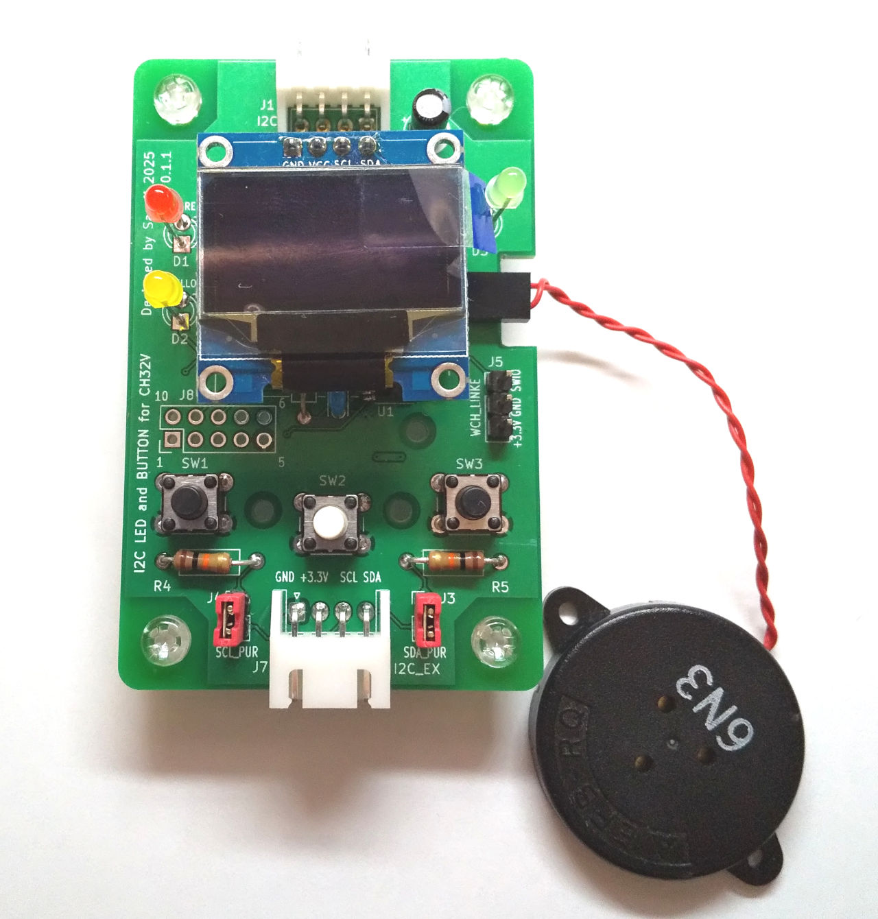
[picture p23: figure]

図 3: I2C入力装置にOLEDと圧電ブザーを接続したもの

以下のいずれかが必要です。

- 0.96インチ128x32または128x64 グラフィックディスプレイOLED (SSD1306コントローラ互換のもの)
  アドレス: 0x3c (Arduino表記では0x78)
- 16x2 キャラクターディスプレイLCD (ST7032コントローラ互換のもの)
  アドレス: 0x3e (Arduino表記では0x7c)

### I2C入力装置

LED表示とボタン入力を行えるデバイスが必要です。このデバイスは独自のもので販売されていません。

このデバイスの詳細については以下のページGitHub(https://github.com/bml3mk5/)を参照ください。

  アドレス: 0x41

## USBメモリ

FAT16でフォーマットしたもの

# 取り付け方法

## 実機への取り付け

このカードはスロット2つ分のスペースを占有します。図 2のように実装してください。

スロットI/F6に取り付ければ占有するスペースを1つにできます。

【注意】 他のフロッピーディスクインターフェイスカードと併用しないようにしてください。

## I2Cデバイスの取り付け


図 4: 本カードとI2Cデバイスとの接続例

I2CデバイスをコネクタJ4(I2C)に接続してください。

# 使い方

1. USBメモリ(FAT16でフォーマットしたもの)にフロッピーディスクイメージファイル(.d88形式)をコピーしてください。
2. USBメモリを本カードに接続してください。
3. I2CデバイスをコネクタJ4(I2C)に接続してください。
4. レベル３実機の電源を入れてください。
5. I2CディスプレイにUSBメモリ内部のファイル名が表示されることを確認してください。
6. ボタンを操作してフロッピーディスクイメージファイルを選択してください。
7. フロッピーディスクイメージファイルを選択すると、自動的にマウントを行います。マウントが正常に行われるとレベル３実機からのアクセスが可能になります。実機を再起動してディスクからブートしてください。

# 主な機能

## FD種類

本カードは3種類のフロッピーディスクインターフェースをエミュレートします。

番号 | 概要 | I/Oアドレス | 備考
0 | 5インチ2D | $FF00～$FF07 | MP-1802相当
1 | 5インチ2D | $FF10～$FF17 | 現在対応していません。
2 | 8インチ2D | $FF00～$FF0F | MP-1806相当(未テスト)
3 | 3インチ1S | $FF18～$FF27 | MP-1800/1805相当

FD種類の切り替え方法については5.2メニューモードを参照してください。

### 5インチ2D

フロッピーディスクインターフェースカードMP-1802相当のエミュレートを行います。

ディスクイメージは、40トラック、2サイド、16セクタ、256バイト/セクタ のものに対応します。

### 8インチ2D

フロッピーディスクインターフェースカードMP-1806相当のエミュレートを行います。

ディスクイメージは、77トラック、2サイド、26セクタ、256バイト/セクタ のものに対応します。

*このモードはテストを行っていないため、正常に動作するかは不明です。

### 3インチ1S

フロッピーディスクインターフェースカードMP-1800またはMP-1805相当のエミュレートを行います。

ディスクイメージは、40トラック、2サイド、16セクタ、128バイト/セクタ(単密度) のものに対応します。

決定ボタンでサイド番号(A面とB面)の切り替えができます。

## 動作

- 電源投入時、ディスクイメージがマウントされるまで実機がHALT状態になります。マウントができない場合は最大5秒ほどHALTになります。
- USBメモリを接続していない場合、I/Oポートが無効になります。
- ディスクイメージがマウントされていない場合、I/Oポートは有効ですがディスクが挿入されていない状態となります。
- ディスクイメージがマウントされると、USBメモリのルートディレクトリにL3VFD.INIファイルを作成します。
- 一定時間画面の更新がない場合、I2Cディスプレイの画面が消灯します。

# 操作方法

I2C接続した入力装置から行います。

## ファイル選択モード

I2Cディスプレイに以下のように表示されます。

### 0:ABCDE.D88 (1) (2) 01:0:03 40:2 N (3) (4) (5) (6) (7) (8)ドライブ番号とファイル名（1行目）

左ボタン

決定ボタン

右ボタン

1行目にドライブ番号とファイル名が表示されます。

1. ドライブ番号
- 決定ボタンを押しながら、左または右ボタンを押すとドライブ番号の切り替えができます。
2. ファイル名
- 左ボタンで１つ前のファイルを、右ボタンで１つ後のファイルを選択します。
- 大かっこ([])で囲まれた名前はサブディレクトリです。ここで決定ボタンを押すと、サブディレクトリ内部に入ります。
- [..]は親ディレクトリです。ここで決定ボタンを押すと、１つ上のディレクトリに戻ります。

### ディスクイメージ情報（2行目）

フロッピーディスクイメージファイルを選択すると、自動的にマウントを行います。

マウントが行われると以下の情報が表示されます。

3. トラック番号
4. サイド番号
5. セクタ番号
6. ディスク内の全トラック数
7. サイド数 1:片面 2:両面
8. マウント状態 N:正常にマウント P:正常ライトプロテクトがかかっている E:エラーあり

FD種類に3インチ1Sモードを選択しているときは、決定ボタンでサイド番号(A面とB面)の切り替えができます。

## メニューモード

ファイル選択モードで決定ボタンを長押しするとメニューモードに入ります。

### Create - ファイル作成

.d88イメージファイルを作成します。イメージサイズはFD種類によって決まります。DISK BASICユーザーディスクとしてフォーマットします。

### Settings - 各種設定

各種設定モードに入ります。

1行目に設定項目が、2行目に設定内容が表示されます。

左に表示される矢印がカーソルになります。

決定ボタンを押すとカーソルが移動します。

カーソルが1行目の時、左右ボタンで設定項目を選択します。2行目の時、左右ボタンで設定内容を選択します。

決定ボタンを長押しするとファイル選択モードに戻ります。

#### Disk type - FD種類選択

左右ボタンで種類を選択してください。FD種類については4.1 FD種類を参照。

【注意】ここで選択したFD種類はレベル３実機をリセットした時に反映されます。

#### Seek track – トラックシーク時間の設定

- Calculate time : トラックに到達するまでのシーク時間を計算します。
- Certain time : シーク時間を一定にします。

#### Search sector - セクタ検索時間の設定

- Calculate time : セクタを見つけるまでの検索時間を計算します。
- Certain time : 検索時間を一定にします。

#### Data request - データアクセス時間の設定

- Calculate time : データリクエストが発生する時間を計算します。
- As fast as :なるべく最速でデータリクエストを発生させます。

#### Display Type 1 – ディスプレイの種類1

I2Cグラフィックディスプレイの種類を選択します。対応しているのは以下の通り：

- OLED 128x64 D : 0.96インチ 128x64ドット OLED FFCケーブルが下側(接続ピンが上側)
- OLED 128x64 U : 0.96インチ 128x64ドット OLED FFCケーブルが上側(接続ピンが下側)
- OLED 128x32 R : 0.91インチ 128x32ドット OLED FFCケーブルが右側(接続ピンが左側)
- OLED 128x32 L : 0.91インチ 128x32ドット OLED FFCケーブルが左側(接続ピンが右側)

#### Display Reset – ディスプレイをリセット

決定ボタンを押すとI2Cディスプレイをリセット＆再初期化します。

#### Save and Exit - 保存して終了

設定内容を本体内フラッシュメモリに保存しファイル選択モードに戻ります。

#### Exit - 保存せず終了

設定内容を破棄しファイル選択モードに戻ります。

### EXIT - メニュー終了

メニューモードを終了し、ファイル選択モードに戻ります。

# スイッチとジャンパ

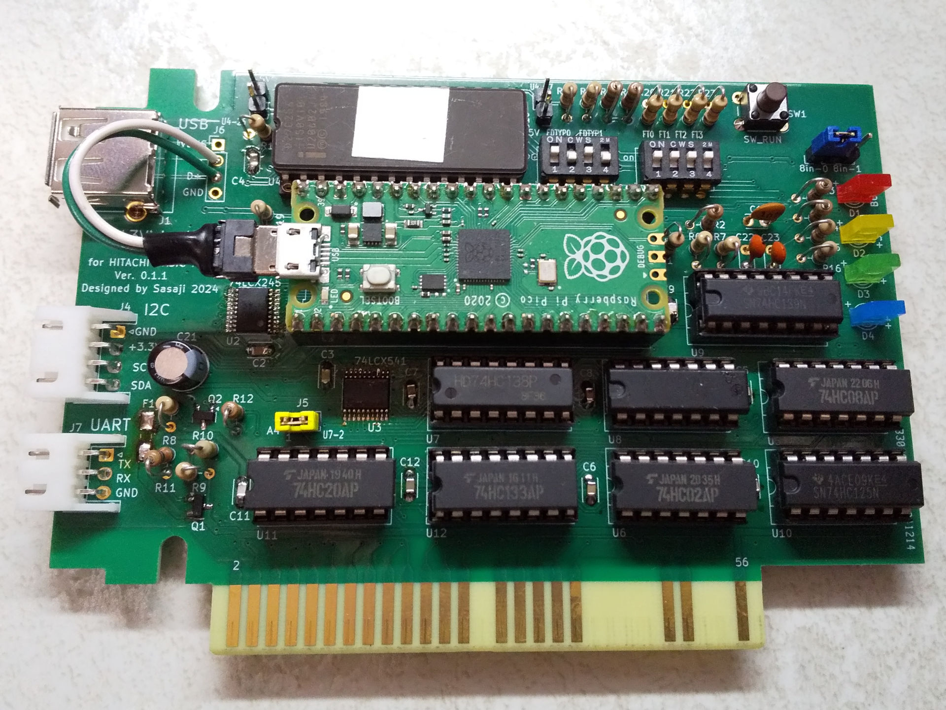
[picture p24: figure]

J9 ROM ピン26 J10 ROM ピン27 SW2 FD種類 選択 SW3 ROM有効 選択

## J7 UART J4 I2Cデバイス 接続 J1 USB Aポート J5 アドレスA4 接続 SW1 Pico RUN ボタン J3 8インチFD アドレス選択J1 USB Aポート

USBメモリを接続します。

## J3 8インチFDアドレス選択

ピン配置は左から1,2,3となります。1-2(8in-0)をショートした時はアドレス$FF00～$FF0F選択、2-3(8in-1)をショートした時はアドレス$FF10～$FF1F選択となります。通常は1-2をショートしてください。

## J4 I2Cデバイス接続

I2Cデバイスを接続します。ピン配置は上からGND, +3.3V, SCL, SDAとなります。SCLがPicoのGPIO5と、SDAがGPIO4と接続しています。

コネクタタイプ: XHコネクタ 4ピン 2.5mmピッチ (QIコネクタ 2.54mmピッチでも接続可能)

## J5 アドレスA4接続

A4信号を有効にするかを選択します。通常はショートしてください。

## J7 UART

シリアル通信用です。ピン配置は上からTX(Output), RX(Input), GNDとなります。TXがPicoのGPIO0と、RXがGPIO1と接続しています。+3.3Vを越えないようにしてください。

通信速度は115200bps.、データフォーマットは、8ビット、パリティなし、1ストップビットとなります。

コネクタタイプ: XHコネクタ 3ピン 2.5mmピッチ (QIコネクタ 2.54mmピッチでも接続可能)

## J9 ROMピン26

ROMのピン26の状態を設定します。ショートさせると”1”になります(Vccに直結します)。

## J10 ROMピン27

ROMのピン27の状態を設定します。ショートさせると”1”になります(Vccに直結します)。

## SW1 Pico RUNボタン

押すとPicoが再起動します。

## SW2 FD種類選択

FD種類の番号を設定します。通常はPico側で設定するため、このスイッチは1,3番をONにしてください。

位置 | ON | OFF
1 | FDTYPE0はPico内部で設定。 2番の設定は無視。 | FDTYPE0はこのスイッチの2番で決める。
2 | FDTYPE0を”1”に固定 | FDTYPE0を”0”に固定
3 | FDTYPE1はPico内部で設定。 4番の設定は無視。 | FDTYPE1はこのスイッチの4番で決める。
4 | FDTYPE1を”1”に固定 | FDTYPE1を”0”に固定

## SW3 ROM有効選択

ブート用ROMのアドレスを選択します。ROMが有効の時、そのイメージはレベル３のアドレス$F800～$FEFFにマッピングされます。通常は1-3番をON,4番をOFFにしてください。

位置 | ON | OFF
1 | FD種類が0の時、ROMのアドレス$0000～$07FFが有効。 | FD種類が0の時、ROM無効。
2 | FD種類が1の時、ROMのアドレス$0800～$0FFFが有効。 | FD種類が1の時、ROM無効。
3 | FD種類が2の時、ROMのアドレス$1000～$17FFが有効。 | FD種類が2の時、ROM無効。
4 | FD種類が3の時、ROMのアドレス$1800～$1FFFが有効。 | FD種類が3の時、ROM無効。

# ファームウェアのアップデート

以下のようにRaspberry Pi Picoへ書き込んでください。

1. レベル３実機の電源をOFFにしてください。
2. USB AポートまたはRaspberry Pi PicoのマイクロUSB BポートとPCと接続してください。接続するとLED D2とD3が点灯します。LED D4は消灯したままになることを確認してください。
3. Raspberry Pi Pico上にあるBOOTSELボタンを押しながら、カード上にあるSW1ボタンを押しPCにRP2フォルダが表示されることを確認してください。
4. ファームウェアプログラムファイル(.uf2ファイル)をRP2フォルダにドロップ(コピー)してください。
5. RP2フォルダが見えなくなればアップデート完了です。USBケーブルをはずしてください。

その他の書き込み方法については、Raspberry Pi公式のドキュメントを参照してください。

# 注意事項

- 他のフロッピーディスクインターフェイスカードと併用しないでください。
- レベル３実機の電源が入っているときは、USBメモリの抜き差しは避けてください。また、USBメモリ以外のものは接続しないでください。
- USBメモリのフォルダはあまり深くしないでください。
- Raspberry Pi Picoファームウェアの更新中はレベル３実機の電源を入れないでください。
- DISK BASIC以外ではテストしていません。
- フロッピーディスクイメージのフォーマットには対応していません。フォーマットはエミュレータなどを使用してください。
- ディスクから起動しない場合
  - FD種類とディスクイメージが一致しているか確認してください。
  - ディスク内にシステムがあるか確認してください。
  - 3インチ1Sモードの場合はサイド番号(A面とB面)を切り替えてシステムが入っている側にして下さい。

# 免責事項

この基板によって発生したいかなる損害についても当方は一切責任を負いません。

この基板を使用するにあたってはすべて自己責任で行ってください。

改訂履歴

初版: 新規作成。

リンク先

この資料や基板データなどはGitHub(https://github.com/bml3mk5/)に置いています。

MailTo: Sasaji (sasaji@s-sasaji.ddo.jp)

Web: http://s-sasaji.ddo.jp/bml3mk5/

X(Twitter): https://twitter.com/bml3mk5/

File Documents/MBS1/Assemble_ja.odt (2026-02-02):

日立MB-S1用

S1VirtualFloppyカード 組立説明書

Designed by Sasaji 2024-2025 Rev. 0.1.1

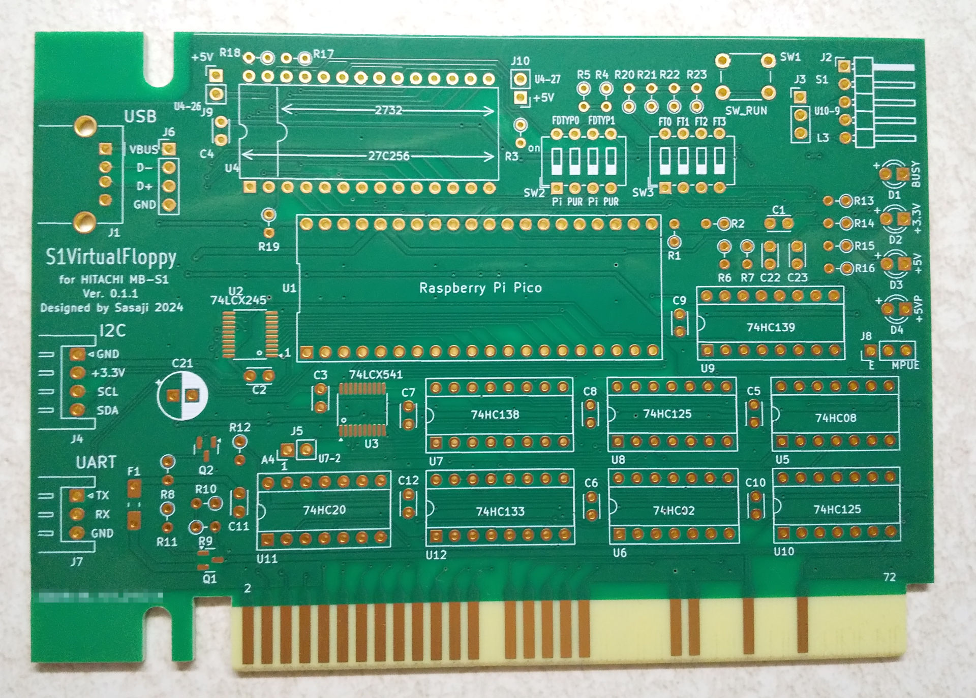
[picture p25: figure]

# 部品表

表 1: 基本部品

番号 | 部品名 | 数量 | 値など
C1 | セラミックコンデンサ | 1 | 1000pF
C2,C3,C5,C6,C7,C8,C9,C10 | セラミックコンデンサ | 8 | 0.1uF
C21 | 電解コンデンサ | 1 | 100uF, 16V～
C22,C23 | セラミックコンデンサ | 2 | 47pF
R1 | カーボン抵抗 | 1 | 150Ω, 1/4W～
R2,R4,R5,R12 | カーボン抵抗 | 4 | 4.7KΩ, 1/6W～
R3 | カーボン抵抗 | 1 | 47KΩ, 1/6W～ (10KΩ～47KΩで使用可能)
R6,R7,R8,R9, R19,R24* | カーボン抵抗 | 6 | 47KΩ, 1/6W～ (22KΩ～47KΩで使用可能)
R10 | カーボン抵抗 | 1 | 470KΩ, 1/6W～
R11 | カーボン抵抗 | 1 | 10KΩ, 1/6W～
F1 | リセッタブルヒューズ / ポリスイッチ | 1 | トリップ電流500mAのもの 表面実装とスルーホールどちらでも可能。
Q1 | MOSFET Pch | 1 | パワーMOSFET Pチャンネル IRLML6402など, SOT23
Q2 | MOSFET Nch | 1 | MOSFET Nチャンネル BSS138など, SOT23
U1 | Raspberry Pi Pico | 1 | ラズパイPico
U2 | CMOSロジックIC | 1 | 74LCX245, SSOP20ピン
U3 | CMOSロジックIC | 1 | 74LCX541, SSOP20ピン
U5 | CMOSロジックIC | 1 | 74HC08, DIP14ピン
U6 | CMOSロジックIC | 1 | 74HC02, DIP14ピン
U7 | CMOSロジックIC | 1 | 74HC138, DIP16ピン
U8,U10 | CMOSロジックIC | 2 | 74HC125, DIP14ピン
U9 | CMOSロジックIC | 1 | 74HC139, DIP16ピン
SW1 | タクトスイッチ | 1 | 6mm x 6mmタイプ
SW2 | DIPスイッチ | 1 | 4回路, DIP8ピン
J3 | ピンヘッダ | 1 | ピンヘッダ 3ピンx1列 2.54mmピッチ ストレート
J4 | XHコネクタ | 1 | 4ピンx1列 2.5mmピッチ Lアングル JST S4B-XH-Aなど
J5 | ピンヘッダ | 1 | ピンヘッダ 2ピンx1列 2.54mmピッチ ストレート
U1_F1,U1_F2 | ピンソケット | 2 | ピンソケット 20ピンx1列 2.54mmピッチ ストレート Raspberry Pi Picoのピンとの接続用
| ジャンパピン | 2 | J3, J5用
U5S, U6S, U8S, U10S | ICソケット | 4 | DIP14ピン 任意
U7S, U9S | ICソケット | 2 | DIP16ピン 任意

* 基板上のシルク印刷に記載がない部品

表 2: 基板上のUSB Aポートを使用する場合に必要な部品

番号 | 部品名 | 数量 | 値など
J1 | USB Aソケット | 1 | 基板取付用USBコネクタ Aタイプ メス (秋月 5075AR-04-WHなど)
| USB microBプラグ | 1 | ケーブル取付用USBコネクタ microBタイプ オス (秋月 MOUSB-5BM103AS など)
| ケーブル | 2 | 上記プラグとJ6とを接続。10cmぐらい USBのD+とD-を接続する必要があります。 (VUSBとGNDは基板上で接続済み)

表 3: ブート用ROMを実装する場合に必要な部品

番号 | 部品名 | 数量 | 値など
C4,C11,C12 | セラミックコンデンサ | 3 | 0.1uF
U4 | ROM | 1 | EPROM DIP28ピン 2764～27256, 27C64～27C256など
U11 | CMOSロジックIC | 1 | 74HC20, DIP14ピン
U12 | CMOSロジックIC | 1 | 74HC133, DIP16ピン
R17,R18,R20,R21,R22,R23 | カーボン抵抗 | 6 | 47KΩ, 1/6W～ (10KΩ～47KΩで使用可能)
SW3 | DIPスイッチ | 1 | 4回路, DIP8ピン
J8 | ピンヘッダ | 1 | ROMを実装する時に必要。 ピンヘッダ 3ピンx1列 2.54mmピッチ ストレート
J9,J10 | ピンヘッダ | 2 | ROMのアドレス切換用 ピンヘッダ 2ピンx1列 2.54mmピッチ ストレート
| ジャンパピン | 2 | J8およびJ9
U4S | ICソケット | 1 | DIP28ピン あったほうが良い
U11S | ICソケット | 1 | DIP14ピン 任意
U12S | ICソケット | 1 | DIP16ピン 任意

表 4: その他の部品（任意）

番号 | 部品名 | 数量 | 値など
D1 | LED | 1 | 3mmΦなど Raspberry Pi PicoがBUSYのとき点灯
D2 | LED | 1 | 3mmΦなど +3.3Vを供給しているとき点灯
D3 | LED | 1 | 3mmΦなど +5V(VUSB)を供給しているとき点灯
D4 | LED | 1 | 3mmΦなど パソコン側から+5V供給しているとき点灯
R13 | カーボン抵抗 | 1 | LED D1を実装する場合に必要。 470Ω～2.2KΩ, 1/4W～ (*)
R14 | カーボン抵抗 | 1 | LED D2を実装する場合に必要。 470Ω～2.2KΩ, 1/4W～ (*)
R15 | カーボン抵抗 | 1 | LED D3を実装する場合に必要。 1KΩ～3.3KΩ, 1/4W～ (*)
R16 | カーボン抵抗 | 1 | LED D4を実装する場合に必要。 1KΩ～3.3KΩ, 1/4W～ (*)
J2 | ピンヘッダ | 1 | ピンヘッダ 5ピンx1列 2.54mmピッチ Lアングル J3と機能は同じです。
J7 | XHコネクタ | 1 | 3ピンx1列 2.5mmピッチ Lアングル JST S3B-XH-A など

* 抵抗値はLEDの明るさに応じて調整してください。

# 追加部品の実装について

この基板は設計ミスがありパッチが必要です。以下の部品を追加で実装してください。

## 抵抗R24の追加

以下の図のように、基板のハンダ面側にプルアップ抵抗R24を追加してください。

この抵抗はHALT時にR/W信号が不安定ならないようにするものです。

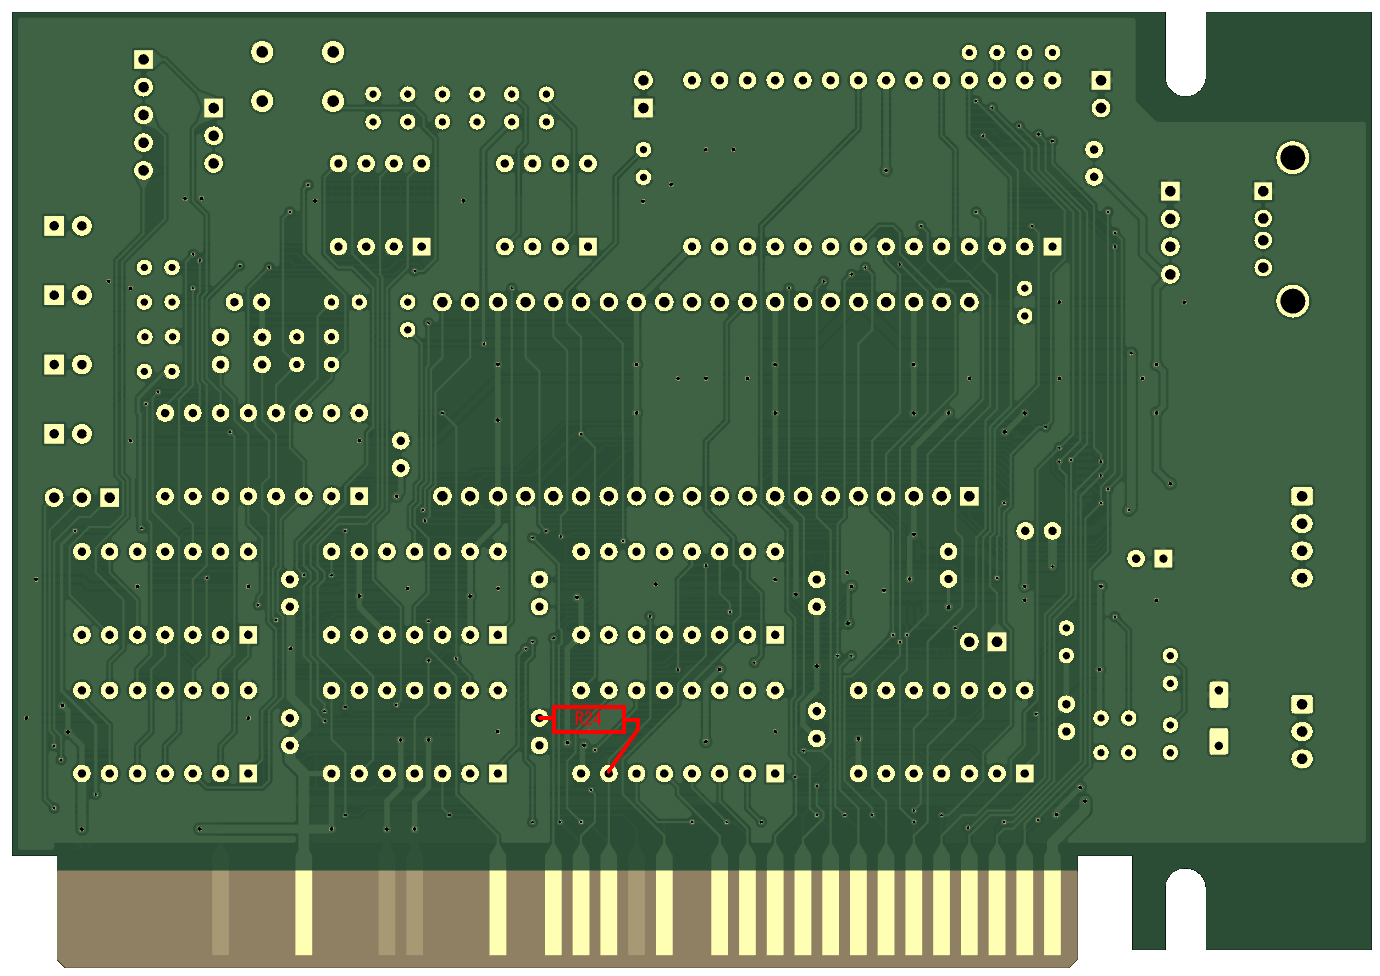
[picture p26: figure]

図 1: 基板のハンダ面（裏側）

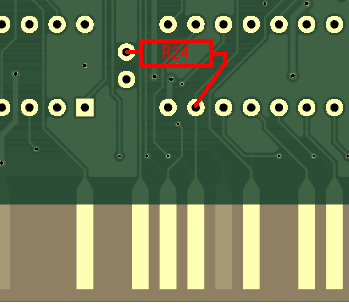
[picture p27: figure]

図 2: R24の取り付け方

# 基板上のUSB Aポートを使用するには

基板上のUSB Aポートを使えるようにするには、J6のD+,D-をRaspberry Pi PicoのUSBポートに接続する必要があります。以下のいずれかの方法で実装してください。

(VBUSとGNDはそれぞれ基板上でつながっているのでここを接続する必要はありません。)

## microBコネクタを使用する方法

表 2の部品を用意してください。

図 3のようにmicroBコネクタが付いたものを作成し、図 4のようにJ6とPicoのmicroBポートに接続します。


図 4: 基板にケーブルをはんだ付け。緑をD+、白をD-に接続している。


図 3: 秋月 MOUSB-5BM103ASとケーブルをはんだ付け。写真では緑(D+)を端子中央(ピン3)に、白(D-)を裏側の端子左側(ピン2)につないでいる。

## Picoに直接はんだ付けする方法

J6とRaspberry Pi Pico裏側にあるTP2(D-),TP3(D+)にケーブルで直接はんだ付けします。

# ブート用ROMについて

Aモード(S1モード)で使用する場合はブート用ROMは不要です。

Bモード(L3モード)の3インチFD(片面単密度)を使用する場合にのみ、ブート用のROMを別途用意する必要があります。ROMの容量は8KB以上のものを推奨します。

## ROMイメージ

ROMの内容は以下のように書き込んだものを用意してください。

表 5: ROMの内容

| アドレス | 概要 | 詳細
0 | $0000～$07FF | 5インチ2DのブートROMイメージ | MP-1802に搭載されているROMのイメージ。 S1のROMに標準で含まれているので無くてもよい。
1 | $0800～$0FFF | 5インチ2DのブートROMイメージ | 上記と同じ。
2 | $1000～$17FF | 8インチ2DのブートROMイメージ | MP-1806に搭載されているROMのイメージ。 テストしていないため動作するかは不明。
3 | $1800～$1FFF | 3インチ1SのブートROMイメージ | MP-1800またはMP-1805に搭載されているROMのイメージ。

- ジャンパーJ8はROMアクセスに使用するクロックを選択するものです。1-2ショートでEクロック(1MHz)を、2-3ショートでMPUEクロック(2MHz)となります。通常は1-2をショートしてください。
- ROMのアクセスタイムは、Eクロック(1MHz)の場合400ns以下、MPUクロック(2MHz)の場合200ns以下のものが必要です。

## 28ピンROMを使用する場合

### 8KBのROM(2764,27C64など)または16KBのROM(27C128など)使用時

ジャンパーJ10(ピン27(PGM)に接続)をショートさせてください。

16KBのROM使用時はジャンパーJ9でアドレスA13の選択ができます。ショートさせると”1”になります。通常はオープンにして下さい。

### 32KBのROM(27C256など)使用時

ジャンパーJ9,J10でアドレスを指定します。J9がA13, J10がA14となります。ショートさせると”1”になります。通常はオープンにしてください。

### 64KBのROM(27C512など)使用時

ピン1(A15)をGNDに接続してください。

ジャンパーJ9,J10の意味は32KBのROMと同じです。

## 24ピンROMを使用する場合

ジャンパーJ9をショートさせてください。ここから+5Vを供給します。ROMを基板上に実装する時はシルク印刷にあるように基板右側に寄せてください。

SW3でどのFD種類の時にROMを有効にするかを設定してください。

# 使い方

取扱説明書(Manual_ja.pdf)を参照してください。

# 免責事項

この基板によって発生したいかなる損害についても当方は一切責任を負いません。

この基板を使用するにあたってはすべて自己責任で行ってください。

改訂履歴

初版: 新規作成。

リンク先

この資料や基板データなどはGitHub(https://github.com/bml3mk5/) (https://github.com/bml3mk5/MP1802Gotek)に置いています。

MailTo: Sasaji (sasaji@s-sasaji.ddo.jp)

Web: http://s-sasaji.ddo.jp/bml3mk5/

X(Twitter): https://twitter.com/bml3mk5/

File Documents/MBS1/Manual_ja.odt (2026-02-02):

日立MB-S1用

S1VirtualFloppyカード　取扱説明書

Designed by Sasaji 2024-2026

Board Revision 0.1.1

Software Version 0.2.2

日立MB-S1用仮想フロッピーディスクカードです。

S1実機からUSBメモリ内部にあるフロッピーディスクイメージに直接アクセスできます。


図 1: 外観


図 2: S1本体に実装したところ

# 必要なもの

## I2Cデバイス

仮想FDの状態表示やUSBメモリ内部のファイルを選択するためにI2Cで接続できるデバイスが必要です。

I2Cデバイスは3.3Vで駆動するものを使用してください。

### I2Cディスプレイ


図 3: I2C入力装置にOLEDと圧電ブザーを接続したもの

以下のいずれかが必要です。

- 0.96インチ128x32 または128x64グラフィックディスプレイOLED (SSD1306コントローラ互換のもの)
  アドレス: 0x3c (Arduino表記では0x78)
- 16x2 キャラクターディスプレイLCD (ST7032コントローラ互換のもの)
  アドレス: 0x3e (Arduino表記では0x7c)

### I2C入力装置

LED表示とボタン入力を行えるデバイスが必要です。このデバイスは独自のもので販売されていません。

このデバイスの詳細については以下のページGitHub(https://github.com/bml3mk5/)を参照ください。

  アドレス: 0x41

## USBメモリ

FAT16でフォーマットしたもの

# 取り付け方法

## 実機への取り付け

このカードを使用するには別途拡張ボードA(MPC-EX01S)などが必要です。カード背面の端子部分が実機背面の外側に出るようにしてください(図 2を参照)。

【注意】 他のフロッピーディスクインターフェイスカードと併用しないようにしてください。

## I2Cデバイスの取り付け

I2CデバイスをコネクタJ4(I2C)に接続してください。


図 4: 本カードとI2Cデバイスとの接続例

# 使い方

1. USBメモリ(FAT16でフォーマットしたもの)にフロッピーディスクイメージファイル(.d88形式)をコピーしてください。
2. USBメモリを本カードに接続してください。
3. I2CデバイスをコネクタJ4(I2C)に接続してください。
4. S1実機の電源を入れてください。
5. I2CディスプレイにUSBメモリ内部のファイル名が表示されることを確認してください。
6. ボタンを操作してフロッピーディスクイメージファイルを選択してください。
7. フロッピーディスクイメージファイルを選択すると、自動的にマウントを行います。マウントが正常に行われるとS1実機からのアクセスが可能になります。実機を再起動してディスクからブートしてください。

# 主な機能

## FD種類

本カードは3種類のフロッピーディスクインターフェースをエミュレートします。

番号 | 種類 | I/Oアドレス | 備考
0 | 5インチ2D | $FF00～$FF07 | MP-1870/1802相当
1 | 5インチ2D | $FF10～$FF17 | 現在対応していません。
2 | 5インチ2HD | $FF00～$FF0F | MB-S1/30や40の2HDまたはMPC-FL03相当
3 | 3インチ1S | $FF18～$FF27 | MP-1800/1805相当

FD種類の切り替え方法については 5.2.2Settings – 各種設定を参照してください。

### 5インチ2D

フロッピーディスクインターフェースカードMP-1870またはMP-1802相当のエミュレートを行います。

ディスクイメージは、40トラック、2サイド、16セクタ、256バイト/セクタ のものに対応します。

### 5インチ2HD

MB-S1モデル30やモデル40に搭載の2HD、あるいはフロッピーディスクインターフェースカードMPC-FL03相当のエミュレートを行います。

ディスクイメージは、77トラック、2サイド、26セクタ、256バイト/セクタ のものに対応します。

### 3インチ1S

フロッピーディスクインターフェースカードMP-1800またはMP-1805相当のエミュレートを行います。

ディスクイメージは、40トラック、2サイド、16セクタ、128バイト/セクタ(単密度) のものに対応します。

決定ボタンでサイド番号(A面とB面)の切り替えができます。

*このモードはL3(B)モード専用になります。

## 動作

- 電源投入時、ディスクイメージがマウントされるまで実機がHALT状態になります。マウントができない場合は最大5秒ほどHALTになります。
- USBメモリを接続していない場合、I/Oポートが無効になります。
- ディスクイメージがマウントされていない場合、I/Oポートは有効ですがディスクが挿入されていない状態となります。
- ディスクイメージがマウントされると、USBメモリのルートディレクトリにS1VFD.INIファイルを作成します。
- 一定時間画面の更新がない場合、I2Cディスプレイの画面が消灯します。

# 操作方法

I2C接続した入力装置から行います。

## ファイル選択モード

I2Cディスプレイに以下のように表示されます。

### 0:ABCDE.D88 (1) (2) 01:0:03 40:2 N (3) (4) (5) (6) (7) (8)ドライブ番号とファイル名（1行目）

左ボタン

決定ボタン

右ボタン

1行目にドライブ番号とファイル名が表示されます。

1. ドライブ番号
- 決定ボタンを押しながら、左または右ボタンを押すとドライブ番号の切り替えができます。
2. ファイル名
- 左ボタンで１つ前のファイルを、右ボタンで１つ後のファイルを選択します。
- 大かっこ([])で囲まれた名前はサブディレクトリです。ここで決定ボタンを押すと、サブディレクトリ内部に入ります。
- [..]は親ディレクトリです。ここで決定ボタンを押すと、１つ上のディレクトリに戻ります。

### ディスクイメージ情報（2行目）

フロッピーディスクイメージファイルを選択すると、自動的にマウントを行います。

マウントが行われると以下の情報が表示されます。

3. トラック番号
4. サイド番号
5. セクタ番号
6. ディスク内の全トラック数
7. サイド数 1:片面 2:両面
8. マウント状態 N:正常にマウント P:正常ライトプロテクトがかかっている E:エラーあり

FD種類に3インチ1Sモードを選択しているときは、決定ボタンでサイド番号(A面とB面)の切り替えができます。

## メニューモード

ファイル選択モードで決定ボタンを長押しするとメニューモードに入ります。

### Create – ファイル作成

.d88イメージファイルを作成します。イメージサイズはFD種類によって決まります。DISK BASICユーザーディスクとしてフォーマットします。

### Settings – 各種設定

各種設定モードに入ります。

ファイル選択モードで決定ボタンを長押しすると設定モードに入ります。

1行目に設定項目が、2行目に設定内容が表示されます。

左に表示される矢印がカーソルになります。

決定ボタンを押すとカーソルが移動します。

カーソルが1行目の時、左右ボタンで設定項目を選択します。2行目の時、左右ボタンで設定内容を選択します。

決定ボタンを長押しするとファイル選択モードに戻ります。

#### Disk type - FD種類選択

左右ボタンで種類を選択してください。FD種類については4.1FD種類を参照。

【注意】ここで選択したFD種類は本体をリセットした時に反映されます。

#### Seek track – トラックシーク時間の設定

- Calculate time : トラックに到達するまでのシーク時間を計算します。
- Certain time : シーク時間を一定にします。

#### Search sector - セクタ検索時間の設定

- Calculate time : セクタを見つけるまでの検索時間を計算します。
- Certain time : 検索時間を一定にします。

#### Data request - データアクセス時間の設定

- Calculate time : データリクエストが発生する時間を計算します。
- As fast as :なるべく最速でデータリクエストを発生させます。

#### Display Type 1 – ディスプレイの種類1

I2Cグラフィックディスプレイの種類を選択します。対応しているのは以下の通り：

- OLED 128x64 D : 0.96インチ 128x64ドット OLED FFCケーブルが下側(接続ピンが上側)
- OLED 128x64 U : 0.96インチ 128x64ドット OLED FFCケーブルが上側(接続ピンが下側)
- OLED 128x32 R : 0.91インチ 128x32ドット OLED FFCケーブルが右側(接続ピンが左側)
- OLED 128x32 L : 0.91インチ 128x32ドット OLED FFCケーブルが左側(接続ピンが右側)

#### Display Reset – ディスプレイをリセット

決定ボタンを押すとI2Cディスプレイをリセット＆再初期化します。

#### Save and Exit – 保存して終了

設定内容を本体内フラッシュメモリに保存しファイル選択モードに戻ります。

#### Exit - 保存せずに終了

設定内容を破棄しファイル選択モードに戻ります。

### Exit – メニュー終了

メニューモードを終了し、ファイル選択モードに戻ります。

# スイッチとジャンパ

J9 ROM ピン26 J10 ROM ピン27 SW2 FD種類 選択 SW3 ROM有効 選択

## J7 UART J4 I2Cデバイス 接続 J1 USB Aポート J5 アドレスA4 接続 SW1 Pico RUN ボタン J2, J3 5インチ2HD アドレス選択 J8 ROMアクセス 信号選択J1 USB Aポート

USBメモリを接続します。

## J2, J3 5インチ2HDアドレス選択

J2とJ3は同じ機能となります。J2は使用しません。

J3は上から1,2,3となります。1-2(S1)をショートした時はアドレス$FF00～$FF0F選択、2-3(L3)をショートした時はアドレス$FF10～$FF1F選択となります。通常は1-2をショートしてください。

J2は上から1,2,3,4,5となります。2,4はGNDです。

## J4 I2Cデバイス接続

I2Cデバイスを接続します。ピン配置は上からGND, +3.3V, SCL, SDAとなります。SCLがPicoのGPIO5と、SDAがGPIO4と接続しています。

コネクタタイプ: XHコネクタ 4ピン 2.5mmピッチ (QIコネクタ 2.54mmピッチでも接続可能)

## J5 アドレスA4接続

A4信号を有効にするかを選択します。通常はショートしてください。

## J7 UART

シリアル通信用です。ピン配置は上からTX(Output), RX(Input), GNDとなります。TXがPicoのGPIO0と、RXがGPIO1と接続しています。+3.3Vを越えないようにしてください。

通信速度は115200bps.、データフォーマットは、8ビット、パリティなし、1ストップビットとなります。

コネクタタイプ: XHコネクタ 3ピン 2.5mmピッチ (QIコネクタ 2.54mmピッチでも接続可能)

## J9 ROMピン26

ROMのピン26の状態を設定します。ショートさせると”1”になります(Vccに直結します)。

## J10 ROMピン27

ROMのピン27の状態を設定します。ショートさせると”1”になります(Vccに直結します)。

## SW1 Pico RUNボタン

押すとPicoが再起動します。

## SW2 FD種類選択

FD種類の番号を設定します。通常はPico側で設定するため、このスイッチは1,3番をONにしてください。

位置 | ON | OFF
1 | FDTYPE0はPico内部で設定。 2番の設定は無視。 | FDTYPE0はこのスイッチの2番で決める。
2 | FDTYPE0を”1”に固定 | FDTYPE0を”0”に固定
3 | FDTYPE1はPico内部で設定。 4番の設定は無視。 | FDTYPE1はこのスイッチの4番で決める。
4 | FDTYPE1を”1”に固定 | FDTYPE1を”0”に固定

## SW3 ROM有効選択

B(L3)モードで起動する際に必要となるブート用ROMのアドレスを選択します。ROMが有効の時、そのイメージはレベル３のアドレス$F800～$FEFFにマッピングされます。通常は1-3番をOFF,4番をONにしてください。

A(S1)モードではこのROMは使用しません。

位置 | ON | OFF
1 | FD種類が0の時、ROMのアドレス$0000～$07FFが有効。 | FD種類が0の時、ROM無効。
2 | FD種類が1の時、ROMのアドレス$0800～$0FFFが有効。 | FD種類が1の時、ROM無効。
3 | FD種類が2の時、ROMのアドレス$1000～$17FFが有効。 | FD種類が2の時、ROM無効。
4 | FD種類が3の時、ROMのアドレス$1800～$1FFFが有効。 | FD種類が3の時、ROM無効。

## J8 ROMアクセス信号選択

ROMアクセスに使用するクロック信号を選択します。J8は左から1,2,3となります。1-2をショートした時はE信号を、2-3をショートした時はMPUE信号選択になります。通常は1-2をショートしてください。

# ファームウェアのアップデート

以下のようにRaspberry Pi Picoへ書き込んでください。

1. S1実機の電源をOFFにしてください。
2. USB AポートまたはRaspberry Pi PicoのマイクロUSB BポートとPCと接続してください。接続するとLED D2とD3が点灯します。LED D4は消灯したままになることを確認してください。
3. Raspberry Pi Pico上にあるBOOTSELボタンを押しながら、カード上にあるSW1ボタンを押しPCにRP2フォルダが表示されることを確認してください。
4. ファームウェアプログラムファイル(.uf2ファイル)をRP2フォルダにドロップ(コピー)してください。
5. RP2フォルダが見えなくなればアップデート完了です。USBケーブルをはずしてください。

その他の書き込み方法については、Raspberry Pi公式のドキュメントを参照してください。

# 注意事項

- 他のフロッピーディスクインターフェイスカードと併用しないでください。
- S1実機の電源が入っているときは、USBメモリの抜き差しは避けてください。また、USBメモリ以外のものは接続しないでください。
- USBメモリのフォルダはあまり深くしないでください。
- Raspberry Pi Picoファームウェアの更新中はS1実機の電源を入れないでください。
- DISK BASIC以外ではテストしていません。
- フロッピーディスクイメージのフォーマットには対応していません。フォーマットはエミュレータなどを使用してください。
- ディスクから起動しない場合
  - FD種類とディスクイメージが一致しているか確認してください。
  - ディスク内にシステムがあるか確認してください。
  - 3インチ1Sモードの場合はサイド番号(A面とB面)を切り替えてシステムが入っている側にして下さい。

# 免責事項

この基板によって発生したいかなる損害についても当方は一切責任を負いません。

この基板を使用するにあたってはすべて自己責任で行ってください。

改訂履歴

初版: 新規作成。

リンク先

この資料や基板データなどはGitHub(https://github.com/bml3mk5/)に置いています。

MailTo: Sasaji (sasaji@s-sasaji.ddo.jp)

Web: http://s-sasaji.ddo.jp/bml3mk5/

X(Twitter): https://twitter.com/bml3mk5/

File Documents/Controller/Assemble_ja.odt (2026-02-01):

I2C LED and BUTTON for CH32V

組立説明書

Designed by Sasaji 2025 Rev. 0.1.1

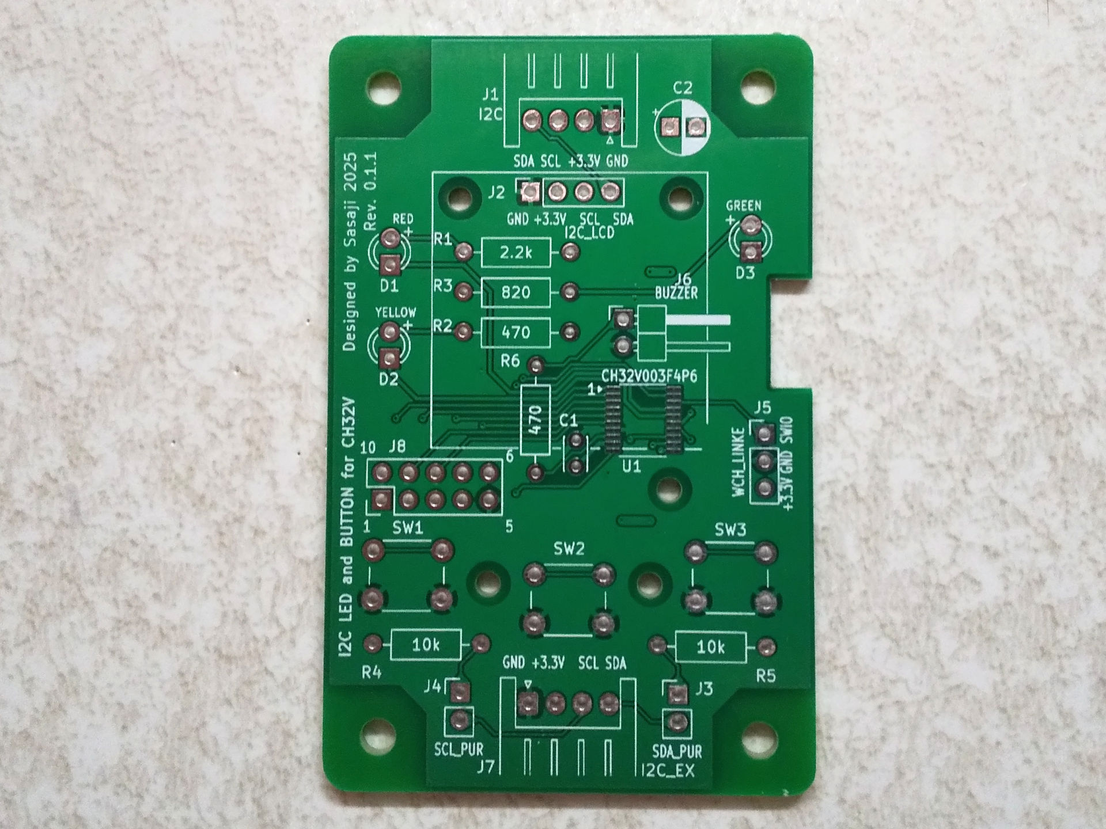
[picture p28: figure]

# 部品表

表 1: 基本部品

番号 | 部品名 | 数量 | 値など
C1 | セラミックコンデンサ | 1 | 0.1uF
C2 | 電解コンデンサ または セラミックコンデンサ | 1 | 10uF, 16V～
D1 | LED | 1 | 3mmΦ (赤色)
D2 | LED | 1 | 3mmΦ (黄色)
D3 | LED | 1 | 3mmΦ (緑色)
R1 | カーボン抵抗 | 1 | 2.2KΩ, 1/4W～ LED D1用 (*)
R2 | カーボン抵抗 | 1 | 470Ω, 1/4W～ LED D2用 (*)
R3 | カーボン抵抗 | 1 | 820Ω, 1/4W～ LED D3用 (*)
R4,R5 | カーボン抵抗 | 2 | 10KΩ, 1/6W～ プルアップ抵抗
R6 | カーボン抵抗 | 1 | 470Ω, 1/4W～ ブザー用
J1 | XHコネクタ | 1 | 4ピンx1列 2.5mmピッチ Lアングル JST S4B-XH-Aなど
J2 | ピンソケット | 1 | 4ピンx1列 2.54mmピッチ
J3, J4 | ピンヘッダ | 2 | 2ピンx1列 2.54mmピッチ
J5 | ピンヘッダ | 1 | 3ピンx1列 2.54mmピッチ
J6 | 圧電ブザー（ピエゾ素子） | 1 | 注意点2.1を参照してください。
U1 | マイコン | 1 | CH32V003F4P6 SSOP20ピン
SW1,SW2,SW3 | タクトスイッチ | 3 | 6mm
| ジャンパピン | 2 | J3, J4用

(*) LEDの明るさに応じて変更してください。

表 2: オプション

番号 | 部品名 | 数量 | 値など
J7 | XHコネクタ | 1 | 4ピンx1列 2.5mmピッチ Lアングル JST S4B-XH-Aなど
J8 | ピンヘッダ | 1 | 5ピン x2列 2.54mm

# 注意点

## J6に接続する圧電ブザーについて

ケースに収める場合は、直接接続かLアングルのXHコネクタを使用を推奨します。Lアングルのピンヘッダを介して接続すると基板からはみ出します。

# マイコンへの書き込み

マイコンへの書き込みは、WCH-LinkEを使用します。

J5は上からSWDIO, GND, +3.3Vとなります。これらとWCH-LinkEの一致するピンを接続してください。

書き込み方法については、WCH-Linkユーティリティ内にあるマニュアルを参照してください。

# 免責事項

この基板によって発生したいかなる損害についても当方は一切責任を負いません。

この基板を使用するにあたってはすべて自己責任で行ってください。

# Webページ

この資料や基板データなどはGitHub(https://github.com/bml3mk5/) (https://github.com/bml3mk5/MP1802Gotek)に置いています。

連絡先：

Sasaji (sasaji@s-sasaji.ddo.jp)

http://s-sasaji.ddo.jp/bml3mk5/

(X(Twitter): https://twitter.com/bml3mk5)

# 改訂履歴

初版: 新規作成。

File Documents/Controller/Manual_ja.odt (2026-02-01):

I2C LED and BUTTON for CH32V

取扱説明書

Designed by Sasaji 2025 Rev. 0.1.1

I2Cを介してLEDとブザーを制御し、ボタンの押下状態を取得できるデバイスです。

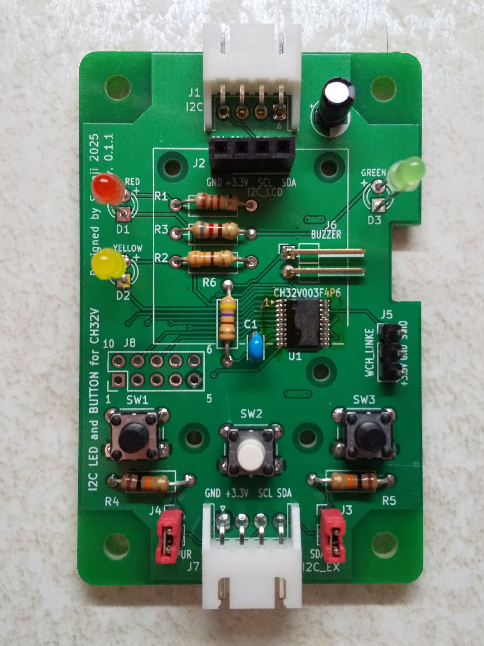
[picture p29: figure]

図 1: 実装例

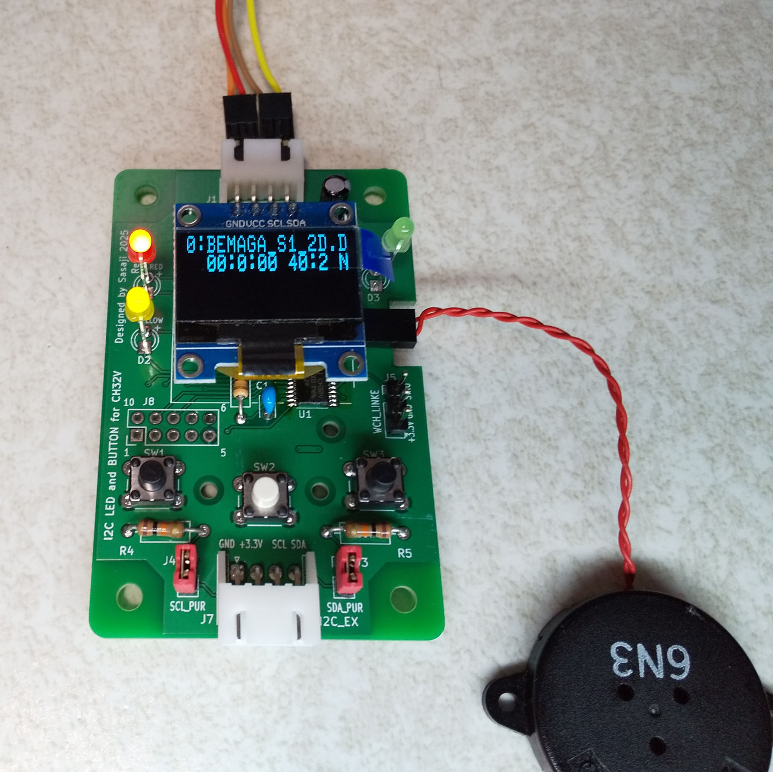
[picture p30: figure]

図 2: 0.96インチのOLEDと圧電ブザーを取り付けたところ

# I2Cの仕様

7ビットアドレスのみサポートしています。

スレーブアドレス: 0x41 (Arduino環境では0x82)

通信速度： ～400kbps.

## ライト時

LEDの点灯制御、およびブザー音の再生指示を行います。

- フォーマット

7ビットアドレス（ライト） | ライトデータ（8ビット）

- 書き込むデータの各ビットの意味

ビット | 0を指定した時 | 1を指定した時
0 | x | x
1 | x | x
2 | x | x
3 | x | x
4 | x | x
5 | x | ブザー音再生 LED D3(緑色)がフラッシュ 再生後、0に戻ります。
6 | LED D2(黄色) Off | LED D2(黄色) On
7 | LED D1(赤色) Off | LED D1(赤色) On

## リード時

ボタンの押下状態を取得します。

- フォーマット

7ビットアドレス（リード） | リードデータ（8ビット）

- データの各ビットの意味

ビット | 0の時 | 1の時
0 | ボタンSW1押していない | ボタンSW1押している
1 | 不定 | 不定
2 | 不定 | 不定
3 | ボタンSW3押していない | ボタンSW3押している
4 | ボタンSW2押していない | ボタンSW2押している
5 | ブザー音再生していない | ブザー音再生している
6 | LED D2(黄色) 消灯している | LED D2(黄色) 点灯している
7 | LED D1(赤色) 消灯している | LED D1(赤色) 点灯している

# ジャンパとコネクタ

## J1 I2Cポート

J2 OLED接続 J8 拡張用 J3 SDAプルアップ J4 SCLプルアップ J1 I2Cポート J6 ブザー接続 J5 マイコン書込み J7 I2C延長用

I2Cマスターと接続します。

各ピンは左からSDA,SCL,+3,3V,GNDとなります。

## J2 OLED接続

0.96インチのOLEDを接続するための端子です。

各ピンは左から+3.3V,GND,SCL,SDAとなります。

## J3,J4 プルアップピン

SCL,SDAにプルアップ抵抗を接続する端子です。プルアップする場合はここをショートしてください。

## J5 マイコン書込み

WCH-LinkEと接続します。各ピンは上からSWIO,GND,+3.3Vとなります。

## J6 ブザー接続

圧電ブザーを接続するための端子です。

## J7 I2C延長用

別のI2Cデバイスを接続するための延長用の端子です。

## J8 拡張用

マイコンのGPIOに接続しています。各ピンは左下から1,2,3,4,5、左上から10,9,8,7,6となります。

各ピンの詳細は以下の通りです。

ピン番号 | 接続先
1 | PD4
2 | PD5
3 | PD6
4 | PD7
5 | GND
6 | PD2
7 | PD3
8 | PA2
9 | PA1
10 | +3.3V

# 免責事項

この基板によって発生したいかなる損害についても当方は一切責任を負いません。

この基板を使用するにあたってはすべて自己責任で行ってください。

# Webページ

この資料や基板データなどはGitHub(https://github.com/bml3mk5/)に置いています。

連絡先：

Sasaji (sasaji@s-sasaji.ddo.jp)

http://s-sasaji.ddo.jp/bml3mk5/

(X(Twitter): https://twitter.com/bml3mk5)

# 改訂履歴

初版: 新規作成。

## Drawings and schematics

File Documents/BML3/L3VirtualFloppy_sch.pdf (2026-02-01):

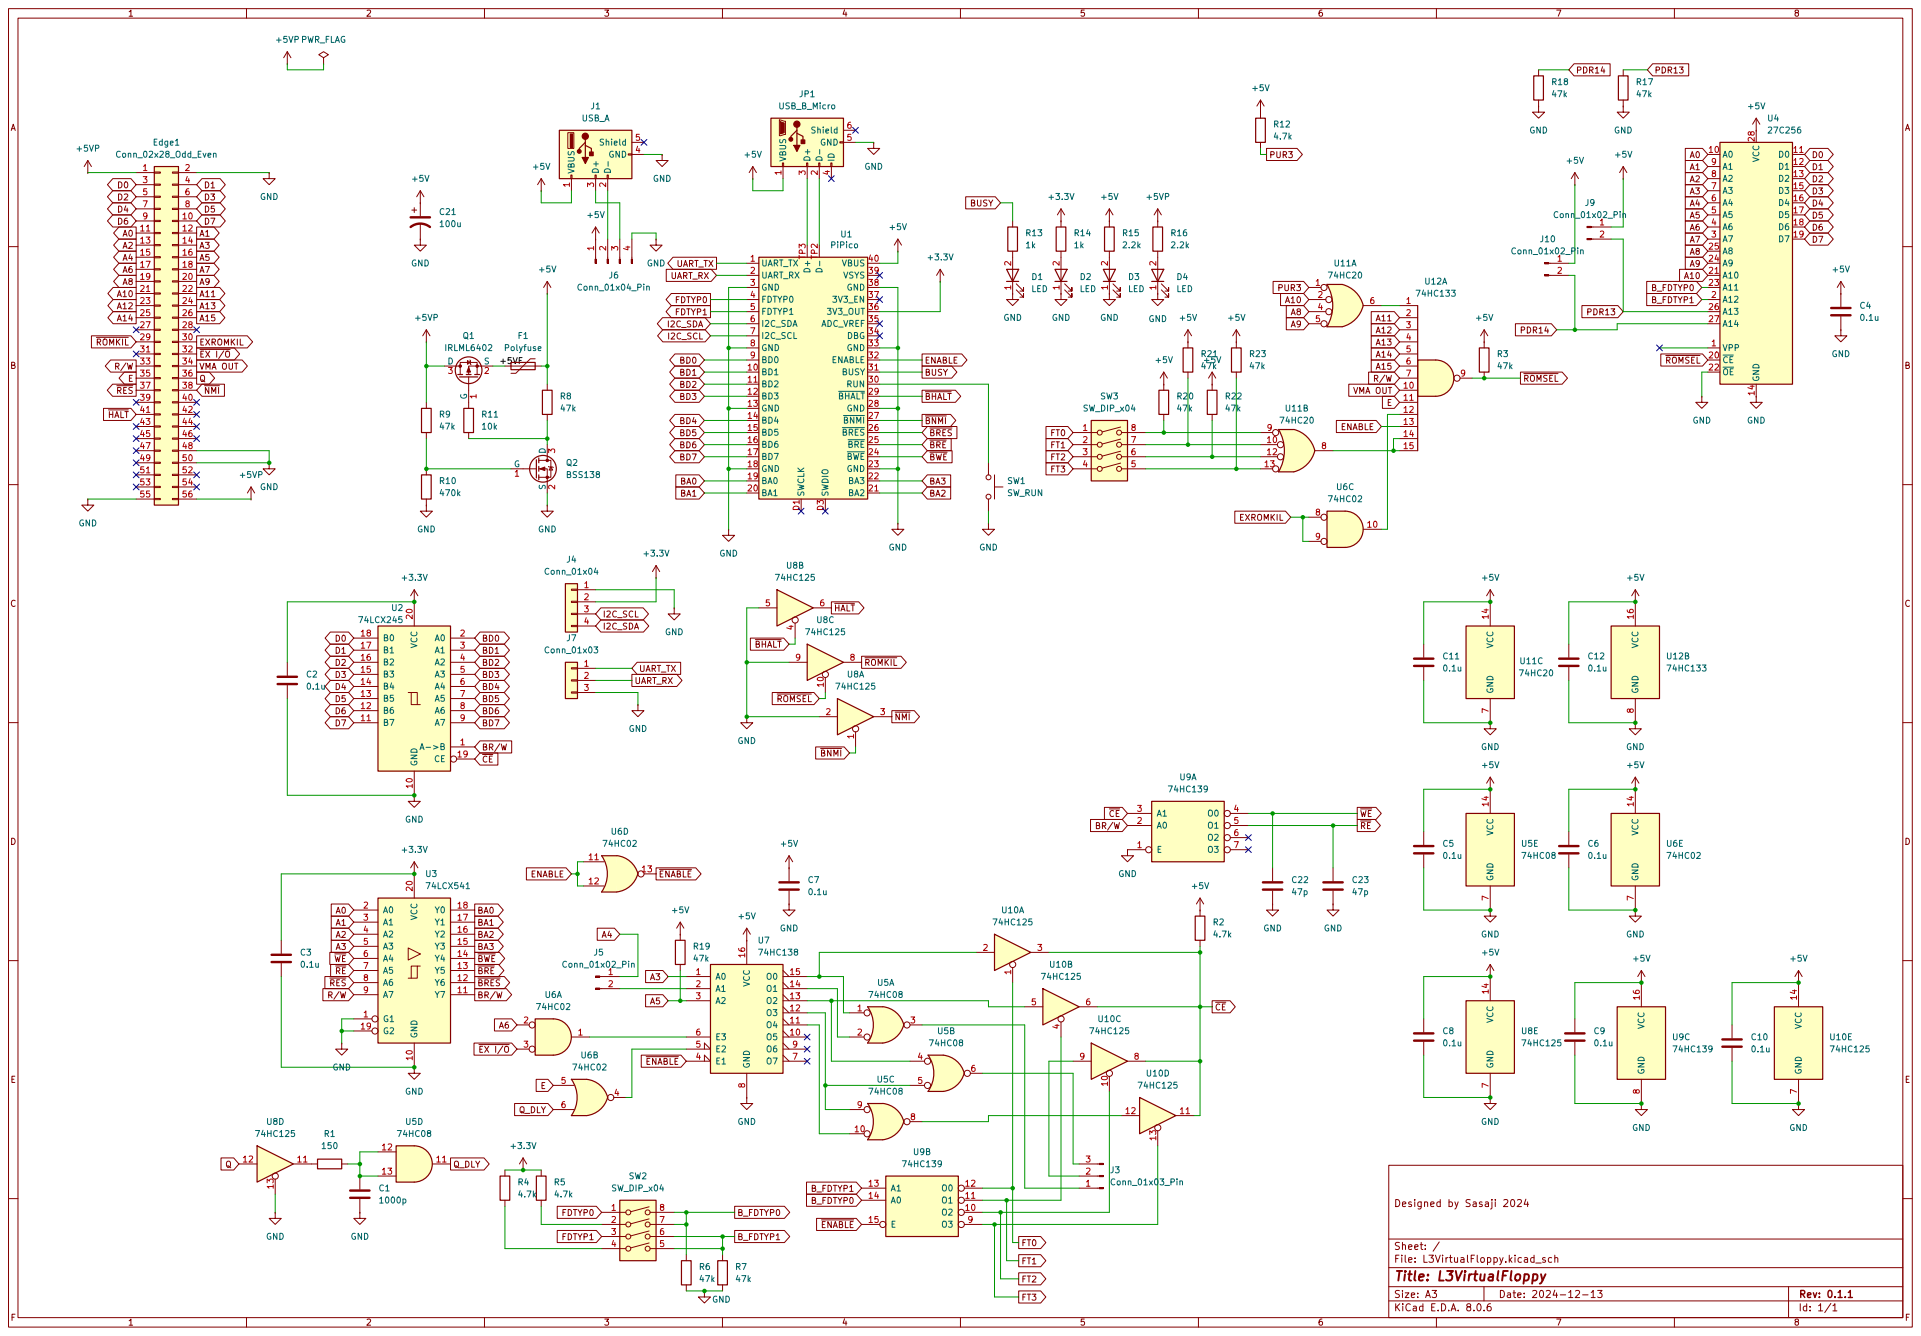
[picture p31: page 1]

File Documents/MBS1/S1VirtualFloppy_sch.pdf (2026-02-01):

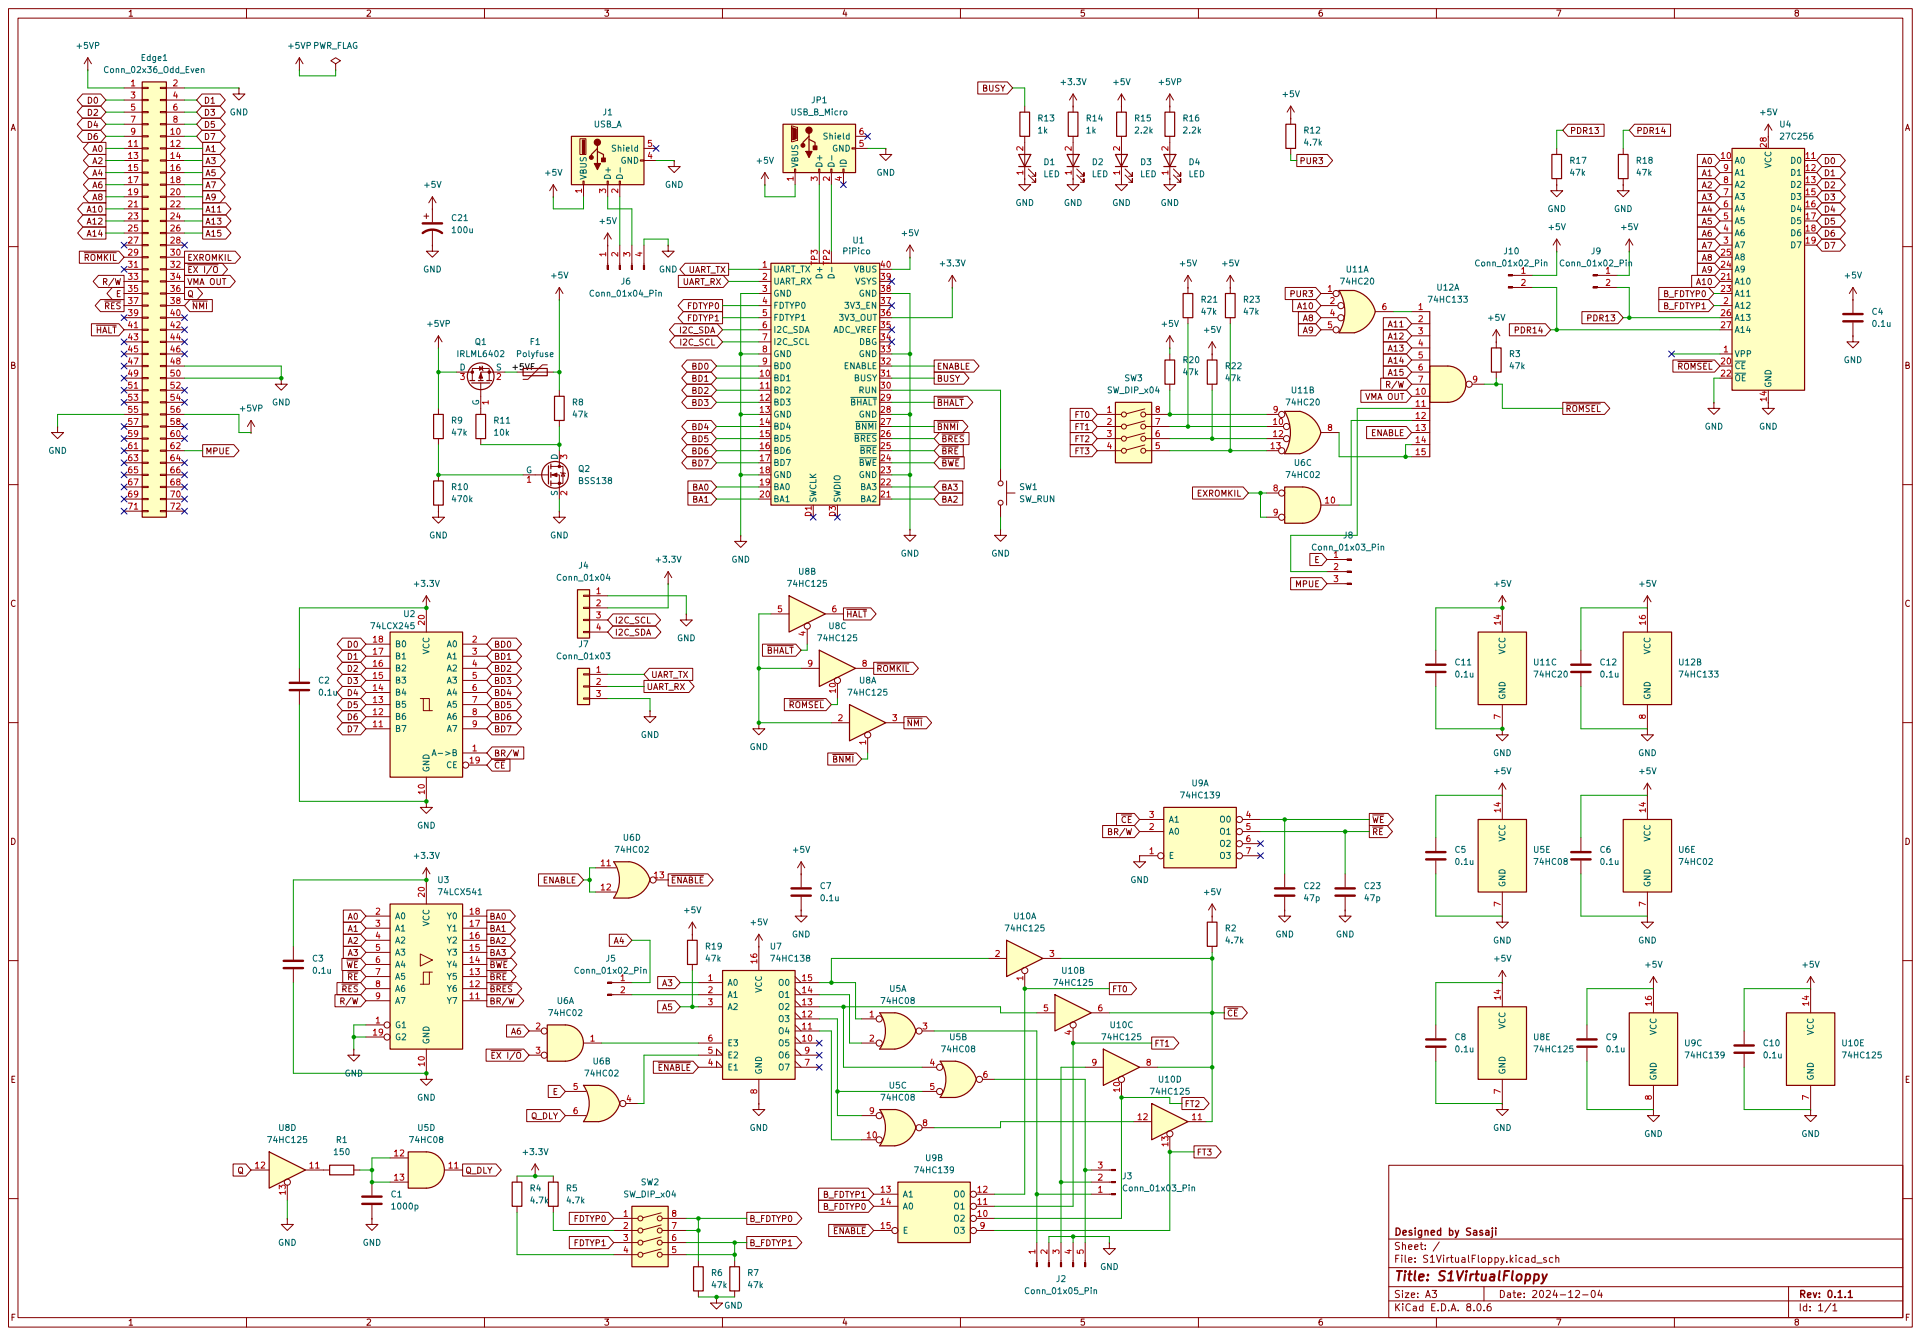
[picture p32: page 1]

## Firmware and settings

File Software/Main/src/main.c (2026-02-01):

/** @file main.c
 *
 * @author Sasaji
 * @brief 
 * @version 0.1
 * @date 2024-10-01
 * 
 * @copyright Copyright (c) Sasaji 2024
 * @copyright Copyright (c) 2019 Ha Thach (tinyusb.org)
 */

#include <stdlib.h>
#include <stdio.h>
#include <string.h>
#include "common.h"
#include "main.h"
#include "msg_bridge.h"
#include <pico/multicore.h>
#include <hardware/structs/bus_ctrl.h>
#include <bsp/board.h>
#include <tusb.h>
#include <hardware/gpio.h>
#include <hardware/irq.h>
#include <pico/sync.h>
#include <pico/binary_info.h>
#include "config.h"
#include "pio_ctrls.h"
#include "msc_app.h"
#include "shell_cmd.h"
#include "disk_drive.h"
#include "disk_d88.h"
#include "fdc_common.h"
#include "event.h"
#include "display.h"

//--------------------------------------------------------------------+
// MACRO CONSTANT TYPEDEF PROTYPES
//--------------------------------------------------------------------+

uint32_t g_c0_current_time_ms;
#ifdef USE_CORE1_CURRENT_TIME
uint32_t MY_CORE1_GROUP(g_c1_current_time_ms);
#endif
#define HALT_SIGNAL_PIN 22

static void halt_signal_init(void);
//static void halt_signal_init_core1(void);

//--------------------------------------------------------------------

#ifdef USE_CORE1
// irq vectors on core1
static uint32_t MY_CORE1_GROUP(core1_vector_table)[32] __aligned(256);

static void core1_main(void);
#endif

//--------------------------------------------------------------------

static void led_blinking_init(void);
static void led_blinking_task(void);

//--------------------------------------------------------------------

static void __no_inline_not_in_flash_func(main_loop)(void)
{
    while (1) {
        // tinyusb host task
        g_c0_current_time_ms = to_ms_since_boot(get_absolute_time());
        tuh_task();
//        msc_app_task();
        shell_cmd_task();
        msg_task();
        disk_d88_task();
        display_task();
        fdc_common_task();
        led_blinking_task();
    }
}

void main_loop_contents_in_shell_cmd(void)
{
    g_c0_current_time_ms = to_ms_since_boot(get_absolute_time());
    tuh_task();
//    msc_app_task();
    msg_task();
    disk_d88_task();
    display_task();
    fdc_common_task();
    led_blinking_task();
}

void main_loop_contents_in_busy_task(void)
{
    g_c0_current_time_ms = to_ms_since_boot(get_absolute_time());
    tuh_task();
    msg_task();
    disk_d88_task();
    display_busy_task();
    fdc_common_task();
    led_blinking_task();
}

//--------------------------------------------------------------------
/*------------- MAIN -------------*/
int main(void)
{
//  stdio_init_all();
//  setup_default_uart();

//  // set highly priority for core1 to be able to access tightly
//  bus_ctrl_hw->priority = BUSCTRL_BUS_PRIORITY_PROC1_BITS;

    board_init();
    config_init();
    event_init();
    halt_signal_init();
    msc_app_init();
    shell_cmd_init();
    msg_init();
    disk_drive_init();
    disk_d88_init();
    display_init();

#ifdef USE_CORE1
    // copy irq vector table for core1
    io_rw_32 vtor_bkup = scb_hw->vtor;
    for(int i=0; i<32; i++) {
        core1_vector_table[i] = ((uint32_t *)vtor_bkup)[i];
    }
    scb_hw->vtor = (io_rw_32)(intptr_t)&core1_vector_table;
    multicore_launch_core1(core1_main);
    scb_hw->vtor = vtor_bkup;

    // wait initialization on core1
    if (multicore_fifo_pop_blocking() != MSG_TYPE_INITIALIZE_DONE) {
        printf("Init Error\n");
        lcd_locate_string(0, 0, "Init Error");
    }
#else
    pio_ctrls_init();
#endif
#if 0
    io_rw_32 vtor_base = scb_hw->vtor;
    printf("Core0: VTOR:%08x\n", vtor_base);
    for(int i=0; i<32; i++) {
        printf(" %02d:%08x", i, ((uint32_t *)vtor_bkup)[i]);
        if ((i & 3) == 3) printf("\n");
    }
#endif

    fdc_common_init();
    // init host stack on configured roothub port
    tuh_init(BOARD_TUH_RHPORT);
    led_blinking_init();

    g_c0_current_time_ms = 0;

    printf("%s Ver.%s\n", APPLICATION, VERSION);

    main_loop();

    return 0;
}

//--------------------------------------------------------------------

#ifdef USE_CORE1
static void MY_CORE1_FUNC(core1_main_loop)(void)
{
    while (1) {
#ifdef USE_CORE1_CURRENT_TIME
        g_c1_current_time_ms = to_ms_since_boot(get_absolute_time());
#endif
        core1_msg_task();
    }
}

void core1_main(void)
{
    // set irq vector table for core1
    scb_hw->vtor = (uintptr_t)&core1_vector_table;

//    halt_signal_init_core1();
    pio_ctrls_init();

#if 0
    printf("Core1: VTOR:%08x\n", scb_hw->vtor);
    for(int i=0; i<32; i++) {
        printf(" %02d:%08x", i, core1_vector_table[i]);
        if ((i & 3) == 3) printf("\n");
    }
#endif
#ifdef USE_CORE1_CURRENT_TIME
    g_c1_current_time_ms = 0;
#endif

    multicore_fifo_push_blocking(MSG_TYPE_INITIALIZE_DONE);

    core1_main_loop();
}
#endif

//--------------------------------------------------------------------+
// TinyUSB Callbacks
//--------------------------------------------------------------------+

void tuh_mount_cb(uint8_t dev_addr)
{
    (void) dev_addr;
}

void tuh_umount_cb(uint8_t dev_addr)
{
    (void) dev_addr;
}

//--------------------------------------------------------------------+

static uint8_t halt_signals;

static int64_t halt_signal_off_cb(alarm_id_t id, void *user_data)
{
    uint8_t signal = (uint8_t)(uint32_t)user_data;
    halt_signal_off(signal);
    return 0;
}

void __not_in_flash_func(halt_signal_off)(uint8_t mask)
{
    halt_signals &= ~mask;
    gpio_put(HALT_SIGNAL_PIN, halt_signals == 0); // negative
}

void __not_in_flash_func(halt_signal_on)(uint8_t mask)
{
    halt_signals |= mask;
    gpio_put(HALT_SIGNAL_PIN, halt_signals == 0); // negative
}

void MY_CORE1_FUNC(halt_signal_on_core1)()
{
    // forcely
    gpio_put(HALT_SIGNAL_PIN, false); // negative
}

bool __not_in_flash_func(is_halt_signal_on)()
{
    return !gpio_get(HALT_SIGNAL_PIN);
}

void halt_signal_init(void)
{
    halt_signals = 0;
    gpio_init(HALT_SIGNAL_PIN);
    gpio_set_dir(HALT_SIGNAL_PIN, true);
    gpio_pull_up(HALT_SIGNAL_PIN);
    halt_signal_on(HALT_SIGNAL_POR);
    event_register_event(4000000, halt_signal_off_cb, HALT_SIGNAL_POR);
    bi_decl(bi_pin_mask_with_name(1u << HALT_SIGNAL_PIN, "HALT# (Out)"));
}

#if 0
void MY_CORE1_FUNC(halt_signal_init_core1)(void)
{
    gpio_init(HALT_SIGNAL_PIN);
    gpio_set_dir(HALT_SIGNAL_PIN, true);
}
#endif

//--------------------------------------------------------------------+

bool some_signals_fdc_is_enable(void)
{
 	return gpio_get(MSC_APP_ENABLE_PIN);
}

//--------------------------------------------------------------------+
// Blinking Task
//--------------------------------------------------------------------+
static alarm_id_t led_init_id;
static uint8_t led_state;
static uint32_t start_ms;

static int64_t led_blinking_init_cb(alarm_id_t id, void *user_data)
{
    board_led_write(0);
    display_led_state(0);
    return 0;
}

void led_blinking_init(void)
{
    led_state = 0;
    start_ms = 0;
    board_led_write(1);
    display_led_state(3);
    led_init_id = event_register_event(500000, led_blinking_init_cb, 0);
}

void __no_inline_not_in_flash_func(led_blinking_task)(void)
{
    const uint32_t interval_ms[2] = { 950, 50 };

    // Blink every interval ms
    if ( g_c0_current_time_ms - start_ms < interval_ms[led_state]) return; // not enough time
    start_ms += interval_ms[led_state];

    led_state = 1 - led_state; // toggle
    board_led_write(led_state);
//    display_led_state(led_state);
}

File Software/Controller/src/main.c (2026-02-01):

/**
 * @file main.c
 * @author Sasaji
 * @brief 
 * @version 0.1
 * @date 2024-10-29
 * 
 * @copyright Copyright (c) 2024
 * 
 */

#include "common.h"
#include "user.h"
#include <debug.h>
#include <stdio.h>
#include <string.h>

int main(void)
{
#ifdef NVIC_PriorityGroup_2
	NVIC_PriorityGroupConfig(NVIC_PriorityGroup_2);
#else
	NVIC_PriorityGroupConfig(NVIC_PriorityGroup_1);
#endif
	SystemCoreClockUpdate();
	Delay_Init();
    USART_Printf_Init(19200);

    // use GPIO Port C
    RCC_APB2PeriphClockCmd(RCC_APB2Periph_GPIOC, ENABLE);
    // use GPIO Port D
    RCC_APB2PeriphClockCmd(RCC_APB2Periph_GPIOD, ENABLE);

    // for LED output and BUTTON input
    Led_Btn_Init();

    // i2c slave
    I2C_Slave_Init();

    __enable_irq();

//  printf("Start\n");

	while (1)
	{
        Led_Btn_Task();
        Delay_Us(1);
	}

    return 0;
}

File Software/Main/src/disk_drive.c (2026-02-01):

/** @file disk_drive.c
 *
 * @author Sasaji
 * @brief 
 * @version 0.1
 * @date 2024-10-01
 * 
 * @copyright Copyright (c) Sasaji 2024
 */

#include "disk_drive.h"
#include <stdio.h>
#include <string.h>
#include "disk_d88.h"
#include "event.h"
#include "common.h"
#include "display.h"
#include "display_disk.h"
#include "fdc_common.h"
#include "config.h"
#include "utils.h"

// time per round (usec.) 300rpm
#define DISK_DRIVE_ONE_ROUND_TIME_2D    200000
// time per round (usec.) 360rpm
#define DISK_DRIVE_ONE_ROUND_TIME_2HD   166666
//
#define DISK_DRIVE_INDEX_TIME             5000
// delay time until motor off (usec.) 
#define DISK_DRIVE_MOTOR_OFF_DELAY     3000000
#define DISK_DRIVE_HEAD_LOADED_TIME	     60000

typedef struct st_disk_drives {
    uint8_t     motor_on;
    uint8_t     index_hole_on;
    uint8_t     drive_type;
    alarm_id_t  motor_off_id;
    uint32_t    motor_time;   ///< motor start/stop time;
    alarm_id_t  index_hole_id;
    uint32_t    one_round_time;
} DISK_DRIVES;
static DISK_DRIVES g_drvs;

#define DISK_DRIVE_MAX_SECTOR_POS   64
typedef struct st_disk_drive {
    uint32_t head_load : 1;
} DISK_DRIVE;
static DISK_DRIVE g_drv[MAX_DRIVES];

//disk_drive_set_status_callback_t disk_drive_set_status_callback = NULL;
//disk_drive_clr_status_callback_t disk_drive_clr_status_callback = NULL;
disk_drive_status_callback_t disk_drive_motor_on_callback = NULL;
disk_drive_status_callback_t disk_drive_motor_off_callback = NULL;
disk_drive_status_callback_t disk_drive_index_on_callback = NULL;
disk_drive_status_callback_t disk_drive_index_off_callback = NULL;

/*======================================================================*/

static int64_t motor_off_cb(alarm_id_t id, void *user_data);
static int64_t index_hole_cb(alarm_id_t id, void *user_data);

/*======================================================================*/

void disk_drive_init()
{
    memset(&g_drvs, 0, sizeof(g_drvs));
    g_drvs.motor_off_id = -1;
    g_drvs.index_hole_id = -1;
    disk_drive_change_type(0);

    memset(&g_drv, 0, sizeof(g_drv));
}

void disk_drive_change_type(int type)
{
    switch(type) {
    case DISK_DRIVE_TYPE_2HD:
        g_drvs.drive_type = DISK_DRIVE_TYPE_2HD;
        g_drvs.one_round_time = DISK_DRIVE_ONE_ROUND_TIME_2HD;
        break;
    default:
        g_drvs.drive_type = DISK_DRIVE_TYPE_2D;
        g_drvs.one_round_time = DISK_DRIVE_ONE_ROUND_TIME_2D;
        break;
    }
}

int disk_drive_get_type()
{
    return g_drvs.drive_type;
}

/*======================================================================*/

bool disk_drive_mount(int drv, int sid_num, const char *path, int offset)
{
    if (disk_d88_mount(drv, sid_num, path, offset) != FR_OK) {
//        disk_drive_clr_status_callback(DISK_DRIVE_MOTOR);
        disk_drive_motor_on_callback();
        return false;
    }
    return true;
}

void disk_drive_unmount(int drv)
{
    disk_d88_unmount(drv);
//    disk_drive_clr_status_callback(DISK_DRIVE_MOTOR);
    disk_drive_motor_off_callback();
}

void disk_drive_append_header(FIL *fp, int image_type)
{
    disk_d88_append_header(fp, config_get_disk_type());
}

/*======================================================================*/

void __not_in_flash_func(disk_drive_motor_on)(int drv)
{
    if (g_drvs.motor_on == 0) {
        if (g_drvs.motor_time < DISK_DRIVE_INDEX_TIME) {
            g_drvs.index_hole_id = event_register_event(DISK_DRIVE_INDEX_TIME - g_drvs.motor_time, index_hole_cb, 0);
        } else {
            g_drvs.index_hole_id = event_register_event(g_drvs.one_round_time - g_drvs.motor_time, index_hole_cb, 1);
        }
        {
            uint32_t t = mod_u32((uint32_t)to_us_since_boot(get_absolute_time()) - g_drvs.motor_time, g_drvs.one_round_time);
            if (t) {
                g_drvs.motor_time = g_drvs.one_round_time - t;
            } else {
                g_drvs.motor_time = t;
            }
        }
    }
    if (g_drvs.motor_on == 1) {
        event_cancel_event(&g_drvs.motor_off_id);
    }
    g_drvs.motor_on = 3;
//    disk_drive_set_status_callback(DISK_DRIVE_MOTOR);
    disk_drive_motor_on_callback();
    lcd_disk_motor(drv, 1);
}

/// @brief Motor off request
void __not_in_flash_func(disk_drive_motor_off)()
{
    if (g_drvs.motor_on == 3) {
        g_drvs.motor_off_id = event_register_event(DISK_DRIVE_MOTOR_OFF_DELAY, motor_off_cb, 0);
        g_drvs.motor_on = 1;
    }
}

bool __not_in_flash_func(disk_drive_is_motor_on)()
{
    return (g_drvs.motor_on != 0);
}

static int64_t __no_inline_not_in_flash_func(motor_off_cb)(alarm_id_t id, void *user_data)
{
    event_cancel_event(&g_drvs.index_hole_id);
    g_drvs.motor_time = mod_u32((uint32_t)to_us_since_boot(get_absolute_time()) + g_drvs.motor_time, g_drvs.one_round_time);
    g_drvs.motor_on = 0;
    g_drvs.motor_off_id = -1;
//    disk_drive_clr_status_callback(DISK_DRIVE_MOTOR);
    disk_drive_motor_off_callback();
    lcd_disk_motor(-1, 0);
    return 0;
}

//void disk_drive_set_head_load(int drv, bool onoff)
//{
//    g_drv[drv].head_load = onoff ? 1 : 0;
//}

static int64_t __no_inline_not_in_flash_func(index_hole_cb)(alarm_id_t id, void *user_data)
{
    uint32_t t = mod_u32((uint32_t)to_us_since_boot(get_absolute_time()) + g_drvs.motor_time, g_drvs.one_round_time);
    if (t < DISK_DRIVE_INDEX_TIME) {
        g_drvs.index_hole_on = 1;
//        disk_drive_set_status_callback(DISK_DRIVE_INDEX);
        disk_drive_index_on_callback();
        g_drvs.index_hole_id = event_register_event(DISK_DRIVE_INDEX_TIME - t, index_hole_cb, 0);
    } else {
        g_drvs.index_hole_on = 0;
//        disk_drive_clr_status_callback(DISK_DRIVE_INDEX);
        disk_drive_index_off_callback();
        g_drvs.index_hole_id = event_register_event(g_drvs.one_round_time - t, index_hole_cb, 1);
    }
    return 0;
}

/*======================================================================*/

uint32_t __not_in_flash_func(disk_drive_get_one_round_time)()
{
    return g_drvs.one_round_time;
}

int __not_in_flash_func(disk_drive_get_current_time)(int delay)
{
    if (delay < 0) delay += g_drvs.one_round_time;
    uint32_t cur_time = delay;
    if (g_drvs.motor_on) {
        // In motor on
        cur_time += (uint32_t)to_us_since_boot(get_absolute_time());
    }
    cur_time += g_drvs.motor_time;
    return (int)mod_u32(cur_time, g_drvs.one_round_time);
}

uint32_t __not_in_flash_func(disk_drive_get_index_hole_remain_time)(int curr_time)
{
    return g_drvs.one_round_time - curr_time;
}

bool __not_in_flash_func(disk_drive_is_index_hole)()
{
    return (g_drvs.index_hole_on != 0);
}
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

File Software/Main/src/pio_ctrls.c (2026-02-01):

/** @file pio_ctrls.c
 *
 * @author Sasaji
 * @brief 
 * @version 0.1
 * @date 2024-10-01
 * 
 * @copyright Copyright (c) Sasaji 2024
 */

#include "common.h"
#include "pio_ctrls.h"
#include <stdio.h>

#include <pico/stdlib.h>
#include <hardware/pio.h>
#include <hardware/clocks.h>
#include <pico/sync.h>
#include <pico/binary_info.h>
#include "pio_ctrls.pio.h"
#include "main.h"
#include "msg_bridge.h"
#include "fdc_common.h"

#define PIO_PARALLEL_START_GPIO 6

// these are constant value but stay in RAM
static const uint8_t MY_CORE1_GROUP(c_pio_parallel_reg_map)[8][16] = {
    // 5inch 2D
   { 0, 1, 2, 3, 4, 4, 4, 4,15,15,15,15,15,15,15,15, },
    // 5inch 2D
   { 0, 1, 2, 3, 4, 4, 4, 4,15,15,15,15,15,15,15,15, },
    // 5inch 2HD
   { 0, 1, 2, 3, 4, 4, 4, 4,14,14,14,14, 5, 5, 5, 5, },
    // 3inch 1S
   { 8, 8, 8, 8, 8, 8, 8, 8, 0, 1, 2, 3, 4, 5, 6, 7, },

    // 5inch 2D
   { 0, 1, 2, 3, 4, 4, 4, 4,15,15,15,15,15,15,15,15, },
    // 5inch 2D
   { 0, 1, 2, 3, 4, 4, 4, 4,15,15,15,15,15,15,15,15, },
    // 5inch 2HD (masked)
   {15,15, 6, 3, 4, 4, 4, 4,14,14,14,14, 5, 5, 5, 5, },
    // 3inch 1S
   { 8, 8, 8, 8, 8, 8, 8, 8, 0, 1, 2, 3, 4, 5, 6, 7, },
};

static uint8_t MY_CORE1_GROUP(disk_type);

pio_parallel_read_t MY_CORE1_GROUP(g_pio_parallel_read);
pio_parallel_write_t MY_CORE1_GROUP(g_pio_parallel_write);

static void pio_parallel_program_init(PIO pio);
static void pio_parallel_read_program_init(PIO pio);
static void pio_parallel_write_program_init(PIO pio);
#ifdef USE_PIO_BUZZER
static void pio_buzzer_program_init(PIO pio);
#endif

//--------------------------------------------------------------------

void pio_ctrls_init()
{
    disk_type = 0;

    PIO pio = pio0;
    pio_parallel_program_init(pio);
    pio_parallel_read_program_init(pio);
    pio_parallel_write_program_init(pio);
#ifdef USE_PIO_BUZZER
    pio_buzzer_program_init(pio);
#endif
    bi_decl(bi_pin_mask_with_name(((1u << PARALLEL_PIN_D_COUNT) - 1) << PIO_PARALLEL_START_GPIO, "DATA BUS (InOut)"));
    bi_decl(bi_pin_mask_with_name(((1u << PARALLEL_PIN_A_COUNT) - 1) << (PIO_PARALLEL_START_GPIO + PARALLEL_PIN_D_COUNT), "ADDR BUS (In)"));
    bi_decl(bi_pin_mask_with_name(1u << (PIO_PARALLEL_START_GPIO + PARALLEL_PIN_WE_N), "WE# (In)"));
    bi_decl(bi_pin_mask_with_name(1u << (PIO_PARALLEL_START_GPIO + PARALLEL_PIN_RE_N), "RE# (In)"));

    pio_sm_set_enabled(pio, PIO_PARALLEL_READ_SM, true);
    pio_sm_set_enabled(pio, PIO_PARALLEL_WRITE_SM, true);
#ifdef USE_PIO_BUZZER
    pio_sm_set_enabled(pio, PIO_BUZZER_SM, true);
#endif

#ifdef PIO_PARALLEL_FDTYPE0_PIN
    // for fd type
    for(int i=PIO_PARALLEL_FDTYPE0_PIN; i<PIO_PARALLEL_FDTYPE0_PIN + PIO_PARALLEL_FDTYPE_COUNT; i++) {
        gpio_init(i);
        gpio_pull_down(i);
        gpio_set_dir(i, true);
    }
    gpio_clr_mask(PIO_PARALLEL_FDTYPE_MASK);
    gpio_put_masked(PIO_PARALLEL_FDTYPE_MASK, (disk_type << PIO_PARALLEL_FDTYPE0_PIN) & PIO_PARALLEL_FDTYPE_MASK);
    bi_decl(bi_pin_mask_with_name(((1u << PIO_PARALLEL_FDTYPE_COUNT) - 1) << PIO_PARALLEL_FDTYPE0_PIN, "FDTYPE (Out)"));
#endif

#ifdef PIO_PARALLEL_DEBUG_PIN
    // for debug
	gpio_init(PIO_PARALLEL_DEBUG_PIN);
	gpio_pull_down(PIO_PARALLEL_DEBUG_PIN);
	gpio_set_dir(PIO_PARALLEL_DEBUG_PIN, true);
	gpio_put(PIO_PARALLEL_DEBUG_PIN, false);
#endif
}

void pio_ctrls_set_disk_type(uint8_t type)
{
    disk_type = type;
    // output to gpio
    gpio_put_masked(PIO_PARALLEL_FDTYPE_MASK, ((uint32_t)disk_type << PIO_PARALLEL_FDTYPE0_PIN) & PIO_PARALLEL_FDTYPE_MASK);
}

void MY_CORE1_FUNC(pio_ctrls_set_disk_type_shift)(bool shift_on)
{
    disk_type = (shift_on ? (disk_type | 0x04) : (disk_type & ~0x04));
}

bool MY_CORE1_FUNC(pio_ctrls_get_disk_type_shift)()
{
    return ((disk_type & 0x04) != 0);
}

//--------------------------------------------------------------------

void pio_parallel_program_init(PIO pio)
{
    uint pin = PIO_PARALLEL_START_GPIO;
    uint pincnt = PARALLEL_PIN_COUNT;

    for(uint i=pin; i<pin+pincnt; i++) {
        gpio_init(i);
        // high impedance
        gpio_set_pulls(i, false, false);
    }
#ifdef PIO_PARALLEL_DEBUG_USE_SIDESET
    gpio_init(pin + PARALLEL_PIN_SIDE);
    gpio_pull_down(pin + PARALLEL_PIN_SIDE);
    gpio_set_dir(pin + PARALLEL_PIN_SIDE, true);
#endif

    for(uint i=pin; i<pin+pincnt; i++) {
        pio_gpio_init(pio, i);
    }
#ifdef PIO_PARALLEL_DEBUG_USE_SIDESET
        pio_gpio_init(pio, pin + PARALLEL_PIN_SIDE);
#endif
}

//--------------------------------------------------------------------

static void MY_CORE1_FUNC(pio_parallel_read_irq_func_sub)(PIO pio, uint8_t addr)
{
#ifdef PIO_PARALLEL_DEBUG_PIN
    gpio_set_mask(1 << PIO_PARALLEL_DEBUG_PIN);
#endif
    if (fdc_common_post_read_tightly_callback(addr)) {
        msg_send_data_to_core0(MSG_TYPE_PARALLEL_READ, addr, 0);
    }
    irq_clear(g_pio_parallel_read.irq);
    pio_interrupt_clear(pio, g_pio_parallel_read.irq_idx);
#ifdef PIO_PARALLEL_DEBUG_PIN
    gpio_clr_mask(1 << PIO_PARALLEL_DEBUG_PIN);
#endif
}

/// @brief irq function of the parallel bus
static void MY_CORE1_FUNC(pio_parallel_read_irq_func)(void)
{
    PIO pio = pio0;
//    while((pio->fstat & (1u << (PIO_FSTAT_RXEMPTY_LSB + PIO_PARALLEL_READ_SM))) != 0) {}
    uint32_t data = pio->rxf[PIO_PARALLEL_READ_SM];   // state machine
    uint8_t addr = ((data >> PARALLEL_PIN_D_COUNT) & ((1u << PARALLEL_PIN_A_COUNT) - 1));
    addr = c_pio_parallel_reg_map[disk_type][addr];
    // read from bus master, so output data
    pio->txf[PIO_PARALLEL_READ_SM] = g_pio_parallel_read.odata[addr];
    pio_parallel_read_irq_func_sub(pio, addr);
}

/// @brief initialize of the parallel bus
/// * data bus has 8bits: base + 0 ... + 7
/// * address bus has 5bits: base + 8 ... + 13
/// * chip select signal is 1bit: base + 14
/// * read/write signal is 1bit: base + 15 
/// @param [in] pio    : PIO instance
void pio_parallel_read_program_init(PIO pio)
{
    uint pin = PIO_PARALLEL_START_GPIO;
    uint pincnt = PARALLEL_PIN_COUNT;
    uint sm = PIO_PARALLEL_READ_SM;
    uint offset = pio_add_program(pio, &pio_parallel_read_program);

    for(int i=0; i<PIO_PARALLEL_REGS; i++) {
        g_pio_parallel_read.odata[i] = 0;
    }
    g_pio_parallel_read.odata[15] = 0xff;
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
